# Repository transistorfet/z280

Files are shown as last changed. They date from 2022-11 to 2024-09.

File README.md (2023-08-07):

Z280 Computer
=============

###### *Started October 29, 2022*

A [series of] computers using the Z280, similar to the [Computie
project](https://jabberwocky.ca/projects/computie/).  The first board is a prototyping board with
the CPU's basic needs (clock/pullup resistors/etc), a 1MB Static RAM, a 1MB Flash chip, plus an
expansion bus that an Arduino can be connected to.  The bus pin assignments match Computie's
Supervisor shield, so the onboard flash chip can be programmed using the same harness as
[Computie](https://github.com/transistorfet/computie/raw/main/hardware/68k-Supervisor).

This repository uses git submodules, and can be cloned using:
```
git clone --recurse-submodules git@github.com:transistorfet/z280.git
```

Z280-SBC Revision 1
-------------------

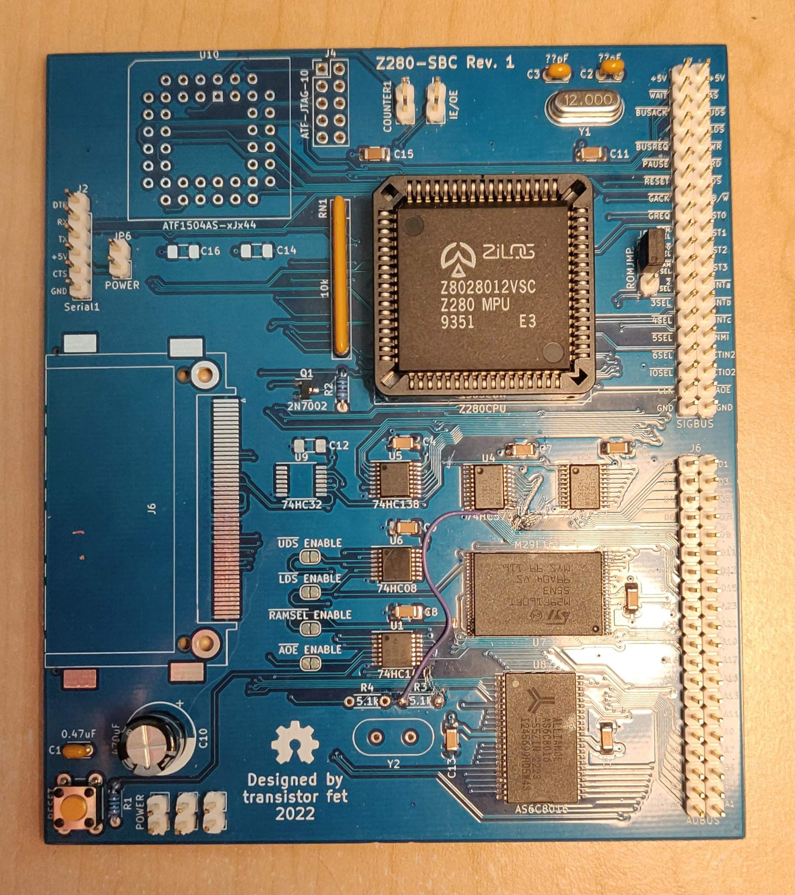
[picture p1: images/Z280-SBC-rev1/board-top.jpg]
Z280-SBC Rev. 1 Assembled Board Top


[Schematics](https://github.com/transistorfet/z280/raw/main/hardware/Z280-SBC/Z280-SBC.pdf)

I designed the first board quickly with the idea of it being rough.  Rather than prototype the CPU
using solderless breadboards, which are prone to electrical faults, I thought I'd design a minimal
board instead, with footprints for various additional components, like memory, a compact flash card
slot, and a CPLD.  I made the mistake of using vias that were 0.4 mm total diameter, which made the
boards more expensive at JLC.  If I redesign the board, I'll probably try to use 0.45 mm vias to
avoid that.

Building the board was pretty quick and easy.  I used the supervisor shield from Computie, along
with the Arduino program
[here](https://github.com/transistorfet/z280/raw/main/software/arduino/Z280Supervisor/) to try to
feed data to the CPU live, without the memory.  I couldn't find documentation on the frequency range
of the CPU, so I used a 12 MHz crystal, which clocks the CPU at 3 MHz.  That's still too fast
though for the Arduino to assert the WAIT signal without an external flip flop to latch it.

I added the memory to the board to see if I could get the CPU executing from there instead, but it
turns out the footprint for the flash chip is upside down, and I installed the chip right way up.  I
didn't notice at first, and while trying to read from the RAM I was getting duplicate numbers in the
test pattern because the A4 address line was being held always low by the flash chip.  The flash
chip was also getting extremely hot when programming the Arduino, but not when idle, oddly enough.
Eventually I clued into the fact that the chip needed to be rotated, and was able to do that using a
hot air rework station to remove the chip.  I reused the same chip, and it seems to work, but there
are other issues with the board, and I'm a bit suspicious of it still.

Using a [logic analyzer](https://www.sparkfun.com/products/18627), I captured some signals after a
reset (I held the reset button while starting a capture and released it during the capture to get
the initial startup).  The bus cycles didn't seem to make sense for the program it should have been
executing, so I programmed the halt instruction into each byte of the first 2K of the flash and ran
it to make sure it halted pretty much right away.  It accessed memory twice before halting instead
of just once, but that might be the instruction pre-fetch (not sure yet).

I was able to use the /DS line wired to the /WAIT line to pause the CPU on the first instruction,
and then inspect the address and data buses at that point, mid bus cycle.  The address bus had the
halt instruction (0x76) on the lower byte, as did the data bus.  The lower address and data buses
are multiplexed on this CPU, and the external latches are supposed to save the address portion when
/AS is low and output them on dedicated address lines wired to the separate address pins of the
memory chips.  Since this was just after a reset, it should have been accessing address 0x0000.  The
address demultiplexing latches should have taken care of this, but it was as if they were open all
the time.  Well, I got the logic backwards on the latch enable pin, so it was was latching when the
/AS line *wasn't* asserted (low).  I must have thought it was negative logic instead of positive
logic, because the /OE pin on the same chip to enable the output is negative logic.

I was able to use one of the inverter gates for the backup clock, which wasn't populated yet, to
invert the /AS line before going into the latch enable pin (positive-logic).  That fixed the
latching issue, and it seems to execute code now, but I can't get much visibility into it yet.

I looked at the ST0-ST3 signals in particular, which output a number corresponding to the
transaction type during each bus cycle.  It seems to be running as expected, accessing memory either
cacheable (0x8) or non-cacheable (0x9), and refreshing memory (0x1).  When the CPU halts, it issues
a halt bus cycle (0x3) and then only performs refresh cycles after that.

I tried adding an EPU instruction, which is a custom Z280 instruction for accessing a coprocessor.
It uses its own transaction type, 0xD for the first word, and 0xC for all subsequent words.  Writing
that instruction into the ROM produced those codes, so it's definitely executing code.  It seemed to
sometimes halt too early though, which turned out to be the attempt at configuring the MMU.  If
there's a problem with the page table that's loaded once the MMU is enabled, it will cause "the
fatal condition" to occur, which halts the CPU.  I had a number of mistakes in the code, and the Z80
assembler I was using was producing some incorrect code.  I switched to SDCC's assembler, which
produces correct code and correct byte orders, and the MMU can now be initialized without 

With that, I set about configuring the UART according to the [Z280 Technical
Manual](https://oldcomputers.dyndns.org/public/pub/rechner/zilog/z280/manual/index.html), which also
requires Timer1 to be configured.  It worked without much trouble, and I was able to print a message
to a serial terminal.

I will need to make a more capable monitor to write to flash so that I can load and jump to code in
RAM instead so I don't need to flash the arduino and then flash the onboard chip.  I can instead
load the data over the serial terminal into ram and run it, the way I can with Computie68k.

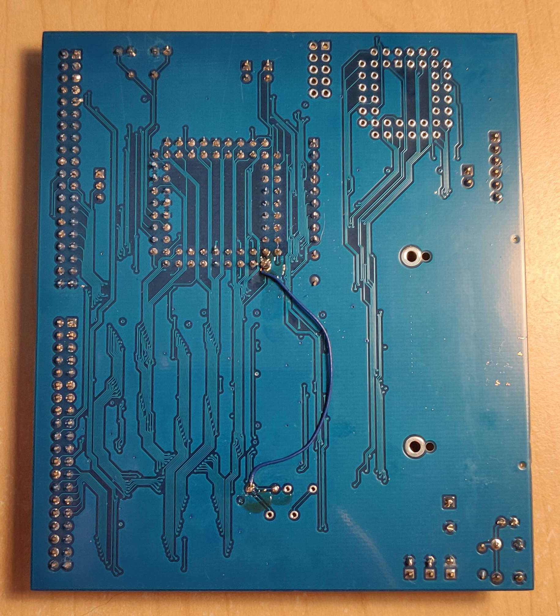
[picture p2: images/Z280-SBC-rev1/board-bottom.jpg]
Z280-SBC Rev. 1 Assembled Board Bottom


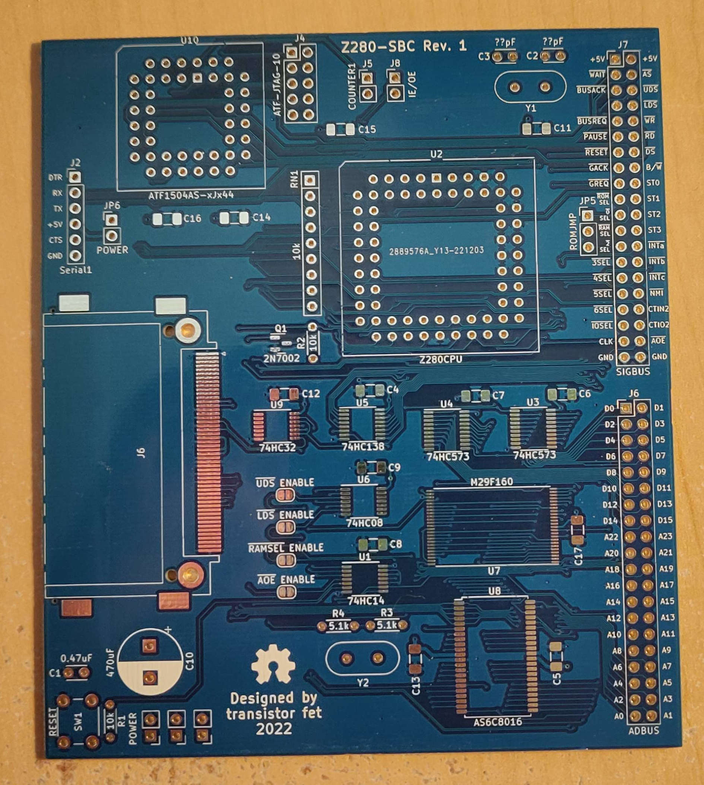
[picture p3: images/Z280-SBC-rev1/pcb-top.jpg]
Z280-SBC Rev. 1 PCB Top


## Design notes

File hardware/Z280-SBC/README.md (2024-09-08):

Z280-SBC
========

Status: DO NOT BUILD (see errata)

Latest: Rev.1

### About
A single board computer with a Z280 CPU, 1MB of static RAM, and 1MB of Flash.

This board has a number of issues described in the errata, which require reworking the board.  The
flash chip needs to be upside down, and the address selection latch's operation is backwards and
needs an extra inverter gate, it or won't run code.  Also, the serial port cannot function correctly
without an external clock circuit to directly supply the UART clock because driving it indirectly
with the Z280's timer causes frequent clock glitches resulting in invalid characters being
sent/received.

[Revision 1 Notes & Errata](revisions/Z280-SBC-rev1-errata.txt)

[Revision 1 Schematic](revisions/Z280-SBC-rev1.pdf)

[Revision 1 Gerbers](revisions/Z280-SBC-rev1.zip)

Z280-SBC board with a blue coloured solder mask and white pin headers, partially populated with the CPLD and CompactFlash slot left off
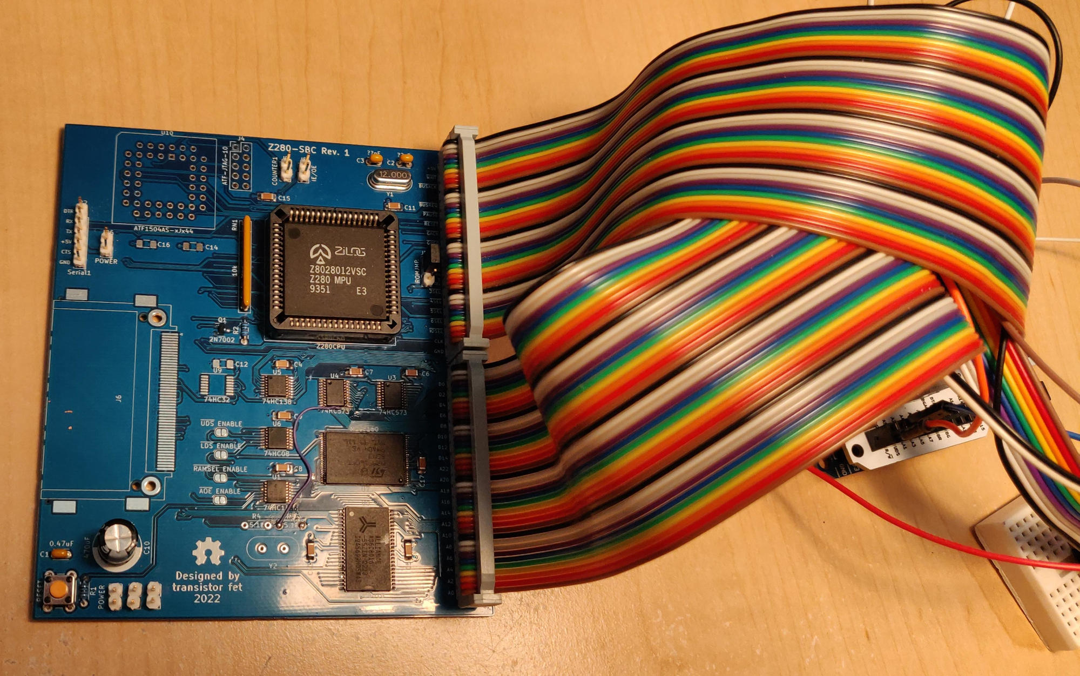
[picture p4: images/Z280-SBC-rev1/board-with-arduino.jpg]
Z280-SBC board with a blue coloured solder mask and white pin headers, and two rainbow/multi-coloured 40-pin ribbon cables connected to an ardunio with the Computie supervisor shield

Z280-SBC board unpopulated, showing the blue solder mask and white silk screen labels

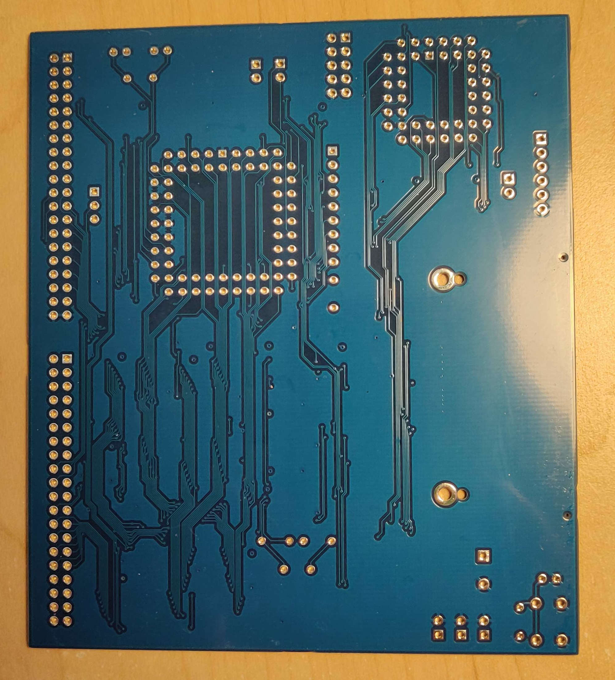
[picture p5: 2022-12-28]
images/Z280-SBC-rev1/pcb-bottom.jpg

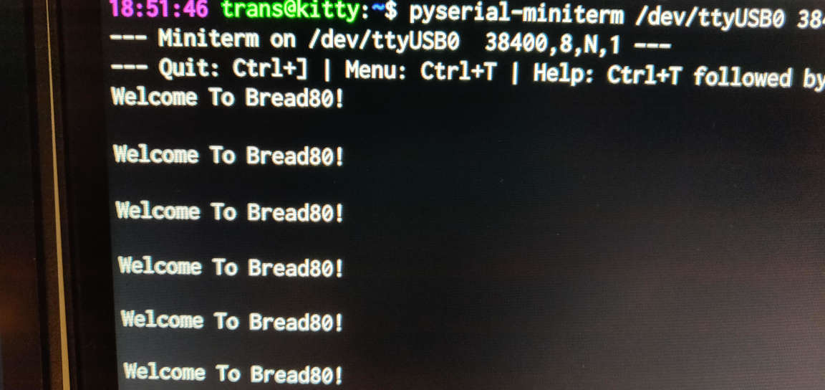
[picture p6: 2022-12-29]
images/Z280-SBC-rev1/z280-uart-message.jpg

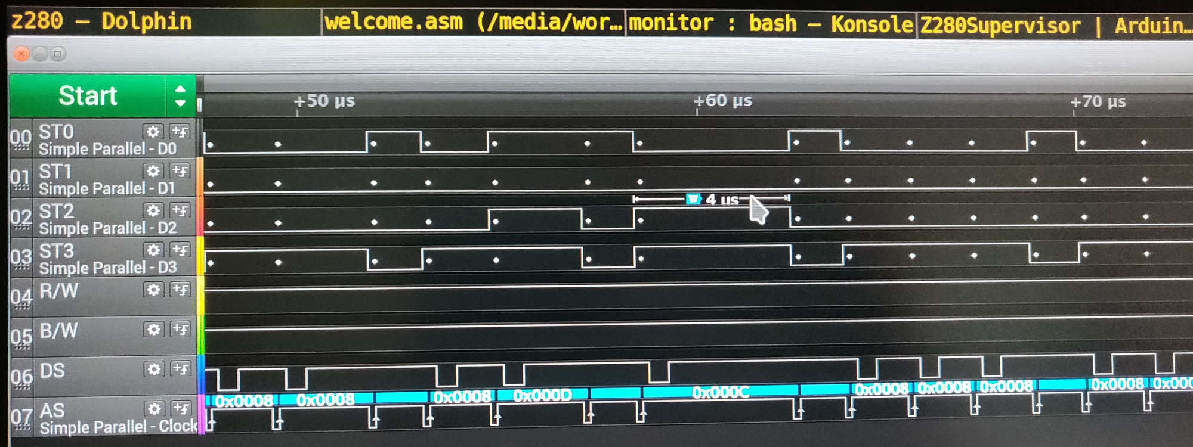
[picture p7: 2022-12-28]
images/Z280-SBC-rev1/z280-logic-analyzer.jpg

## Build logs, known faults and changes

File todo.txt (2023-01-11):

* should you use an MC68692 Serial Controller or something instead of the CPLD, or replace it with the 84 pin PLCC and hook up
  address and data pins (at least 8 data bits) to the I/O, so that you can emulate simple I/O
* CPLD could act as both an interrupt controller and bus coordinator (or rather, the local bus coordinator, where the global
  coordinator would be on the backplane).  This would be if you were trying the multiprocessor feature

* try using interrupts for serial to hopefully transfer data faster than otherwise

* the CPU reads the first 4 bytes of RAM as FFFF FFFF, which seems to still work because there are no other instructions, no int
  handlers that could get in the way, so it still executes code as expected
  Not sure if this is solved now? ^^
* boot in the monitor doesn't work, compiler error so it's commented out
* printf is sometimes glitchy

* to use the arduino, you'd really need to add a flip-flop for the wait state, which the arduino could manually activate via a pin
  on the control signals 40-pin connector to enable latching, but I'm mostly past the need for the arduino besides programming

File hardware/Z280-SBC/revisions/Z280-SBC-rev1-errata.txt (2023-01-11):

Revision 1 Errata and Notes
===========================

- Power connectors are upside-down (ground on top), and are unlabelled

- Somehow I managed to rotate the footprint for the flash chip.  Pin 1 is the bottom right corner instead of the top left.
  It should be possible to rotate the chip and get it working, but I've already mounted the chip the wrong way, and it's
  heated up quite a bit as a result.  Removing and rotating the chip fixed the issue.  It might not be as reliable as it
  should be, but the reversed chip does seem to be working most of the time

- I messed up the logic for latching the addresses with 74HC573s.  It's actually positive logic, so a high on the LE
  line of the will load the data bus into the address bus.  /AS is wired to it because we want it to latch only when /AS
  is low (address an AD bus is valid), which is backwards.  It needs to be inverted before going into LE. 

- the tty connector is rotated 180 degrees, such that the FTDI boards I have must go inward, towards the CPU instead of
  outward from the board.  It's probably because I copied the k30, and that one was already rotated 90 from the usual
  position, to come out of the top of the board

- there seems to be a problem with Timer1 running off the CPU clock when used as the UART clock.  It seems to glitch no
  matter what, when receiving data, regardless of the configuration of Timer1 or the UART .  An external clock wired to
  Timer1 input fixes the issue, but I've repurposed the alternate clock's inverters to fix the latches, so the clock is on
  an external breadboad.

- I put CTIN1 and CTIN2 onto input-only pins of the CPLD, when they should be output pins (input to the CPU, output from
  the CPLD).  I need to use CTIN1 as the alternate clock input

- the CPLD is kind of useless because it doesn't have any extra I/O pins that could be hooked up to other devices, such
  as an I2C connection to other devices, or chip select lines to index devices based on the address lines.  I probably
  should have put the bigger PLCC84 chip on and wired the extra I/O to generic header pins.  Maybe included the data bus
  so that simple I/O devices could be emulated, but that might require too many macrocells and would be better for an FPGA

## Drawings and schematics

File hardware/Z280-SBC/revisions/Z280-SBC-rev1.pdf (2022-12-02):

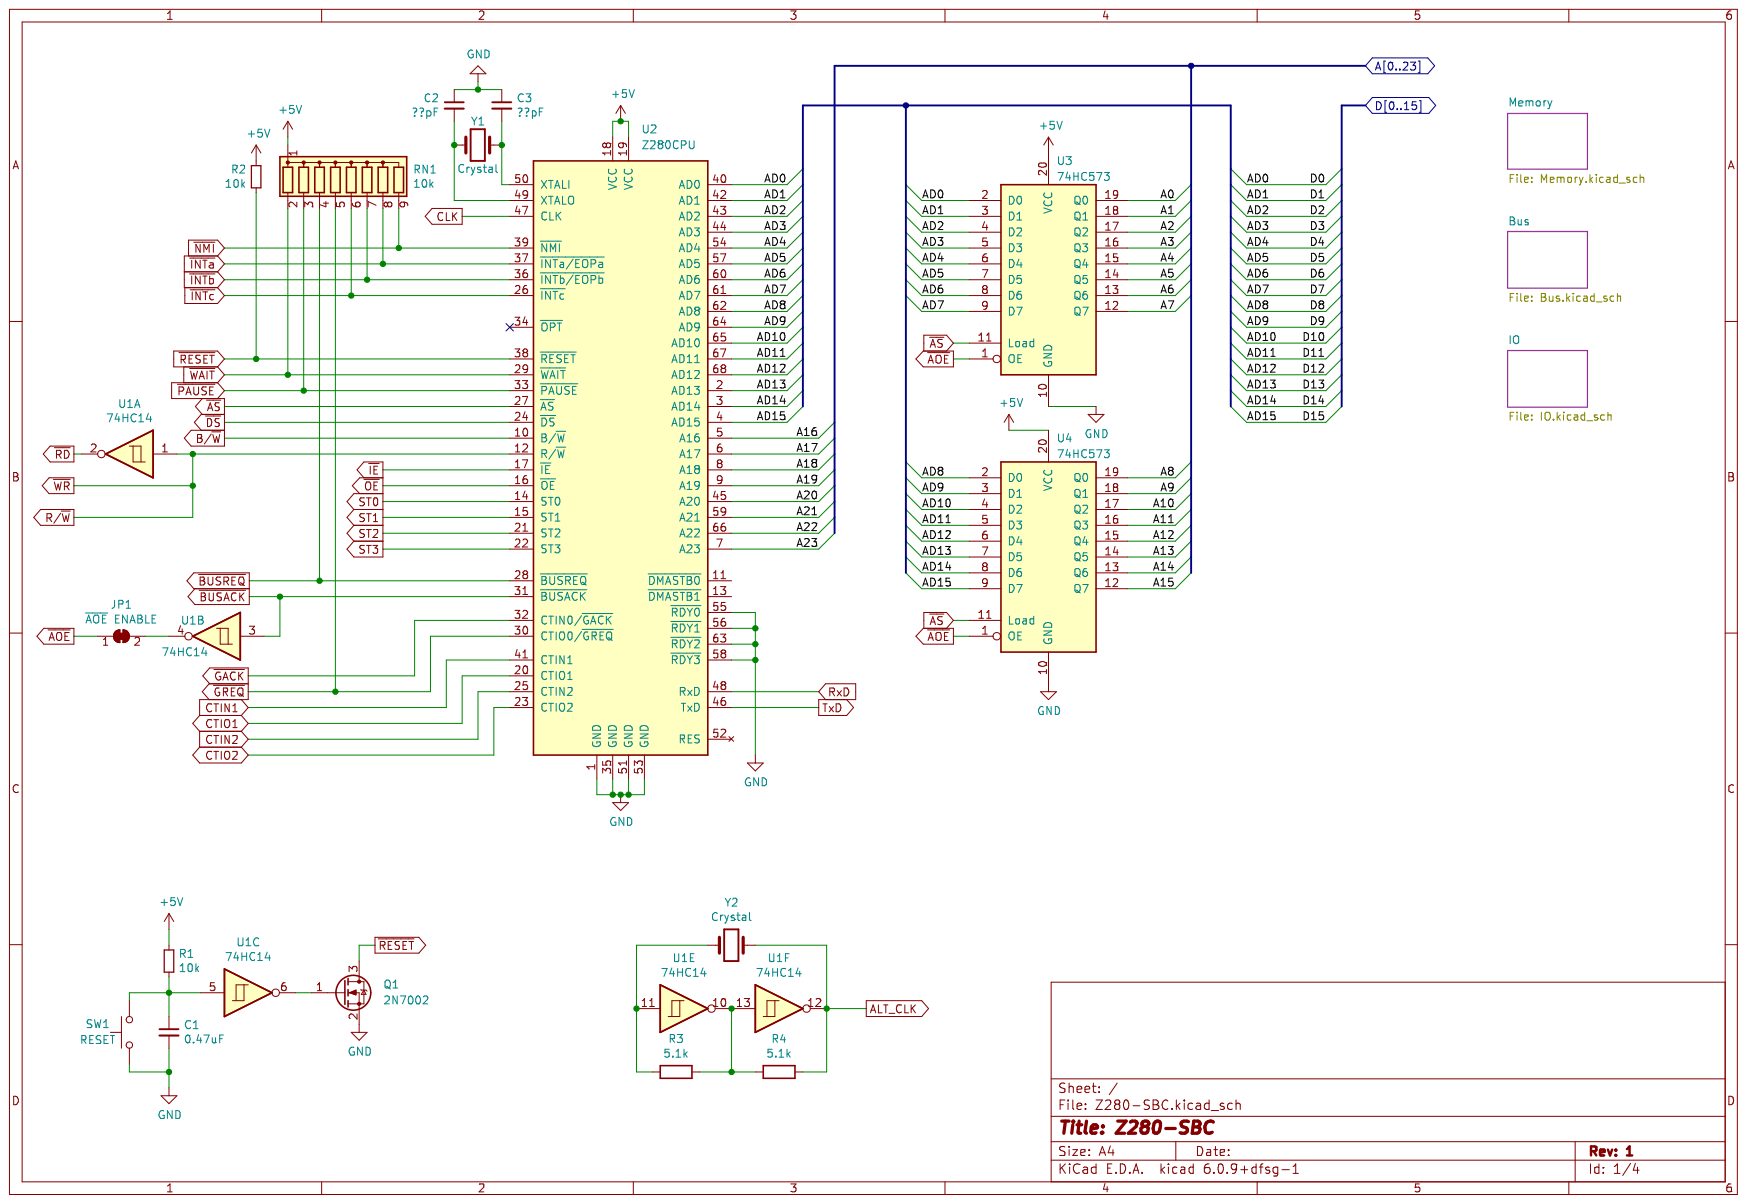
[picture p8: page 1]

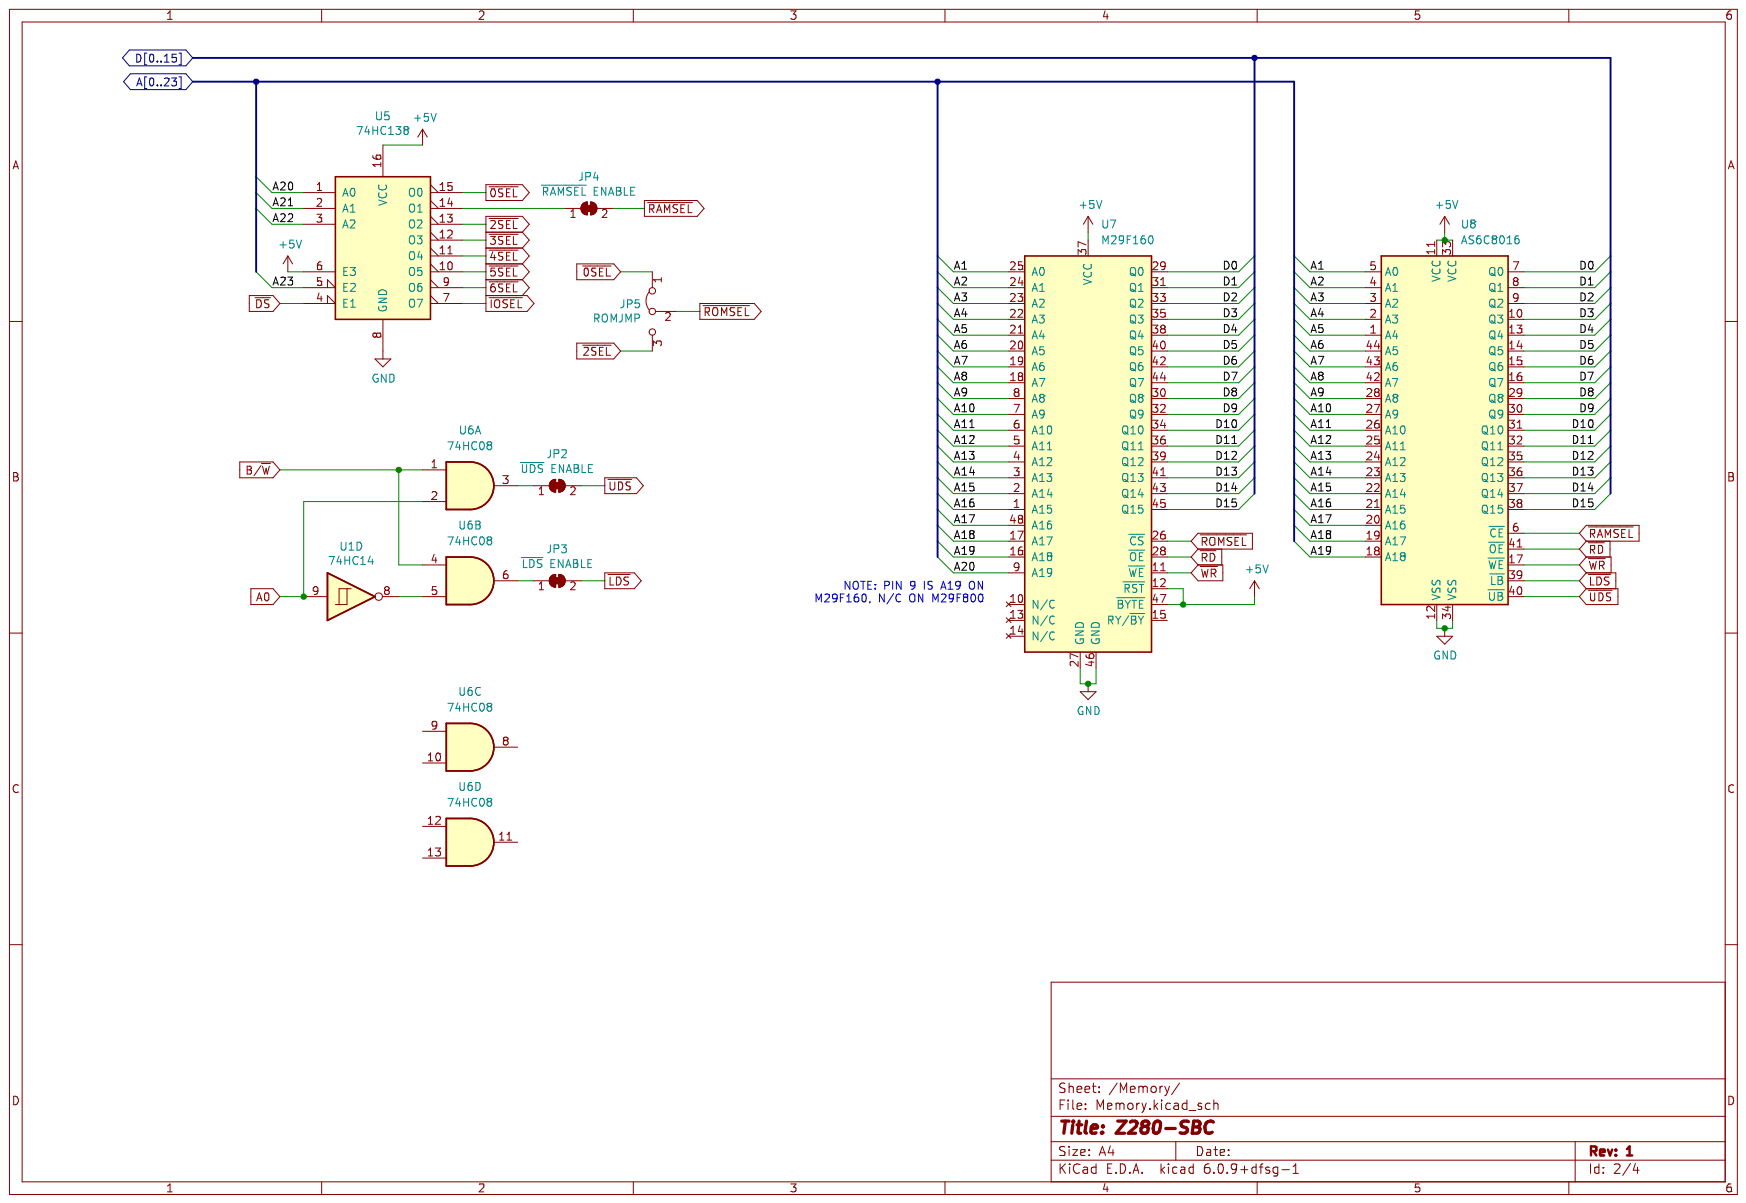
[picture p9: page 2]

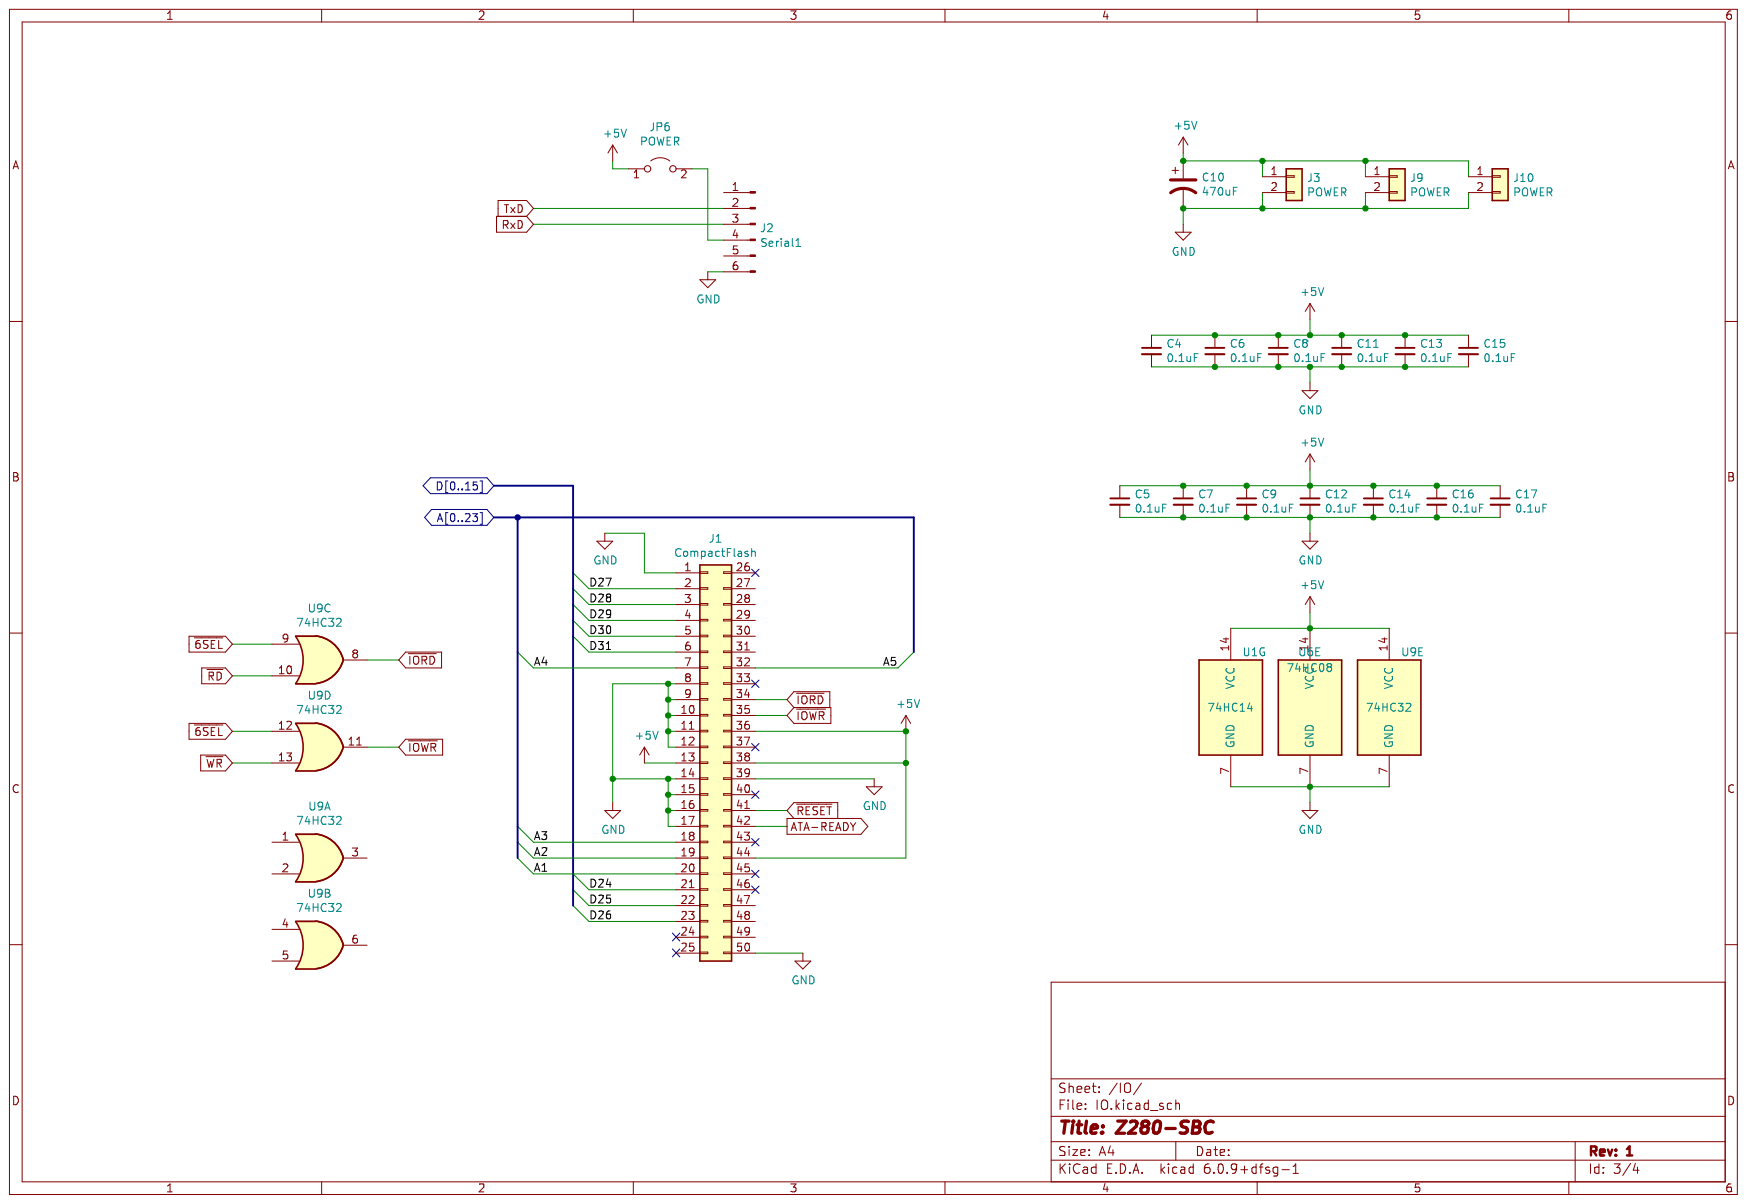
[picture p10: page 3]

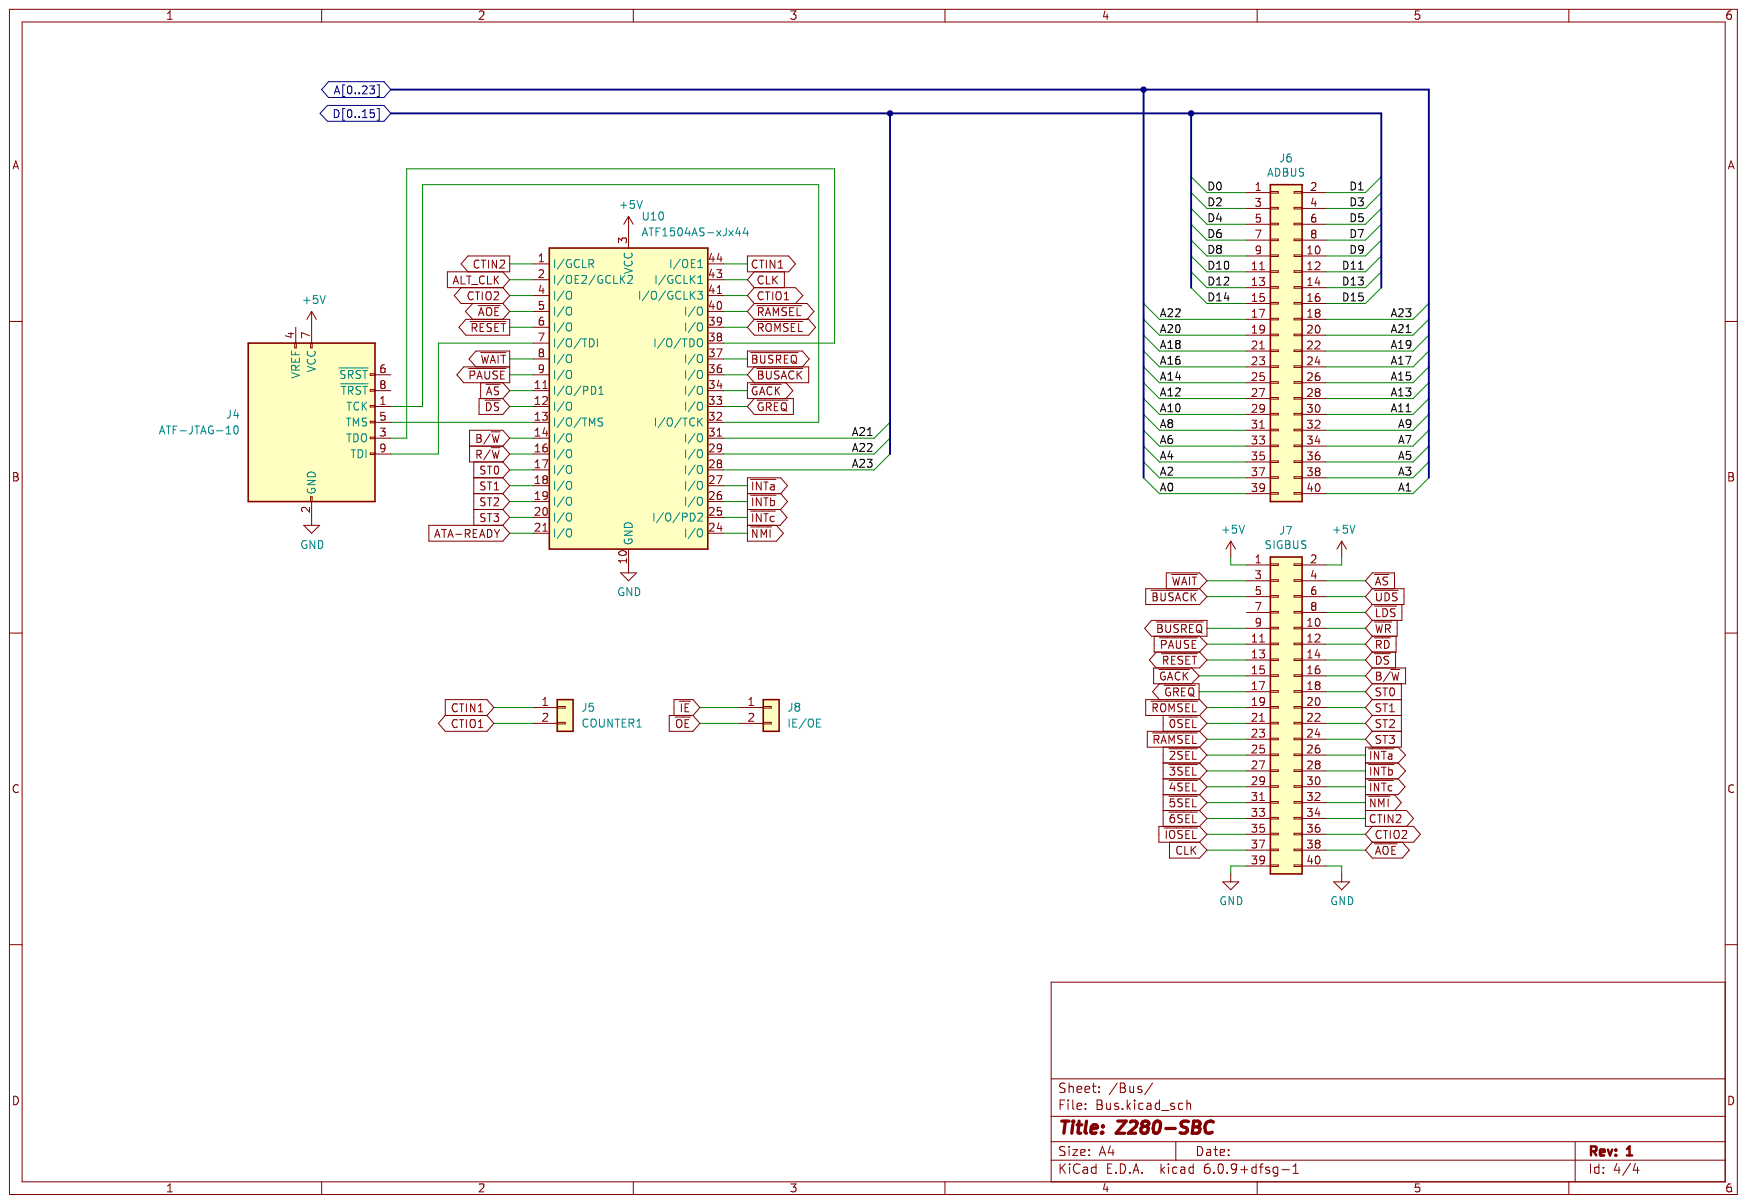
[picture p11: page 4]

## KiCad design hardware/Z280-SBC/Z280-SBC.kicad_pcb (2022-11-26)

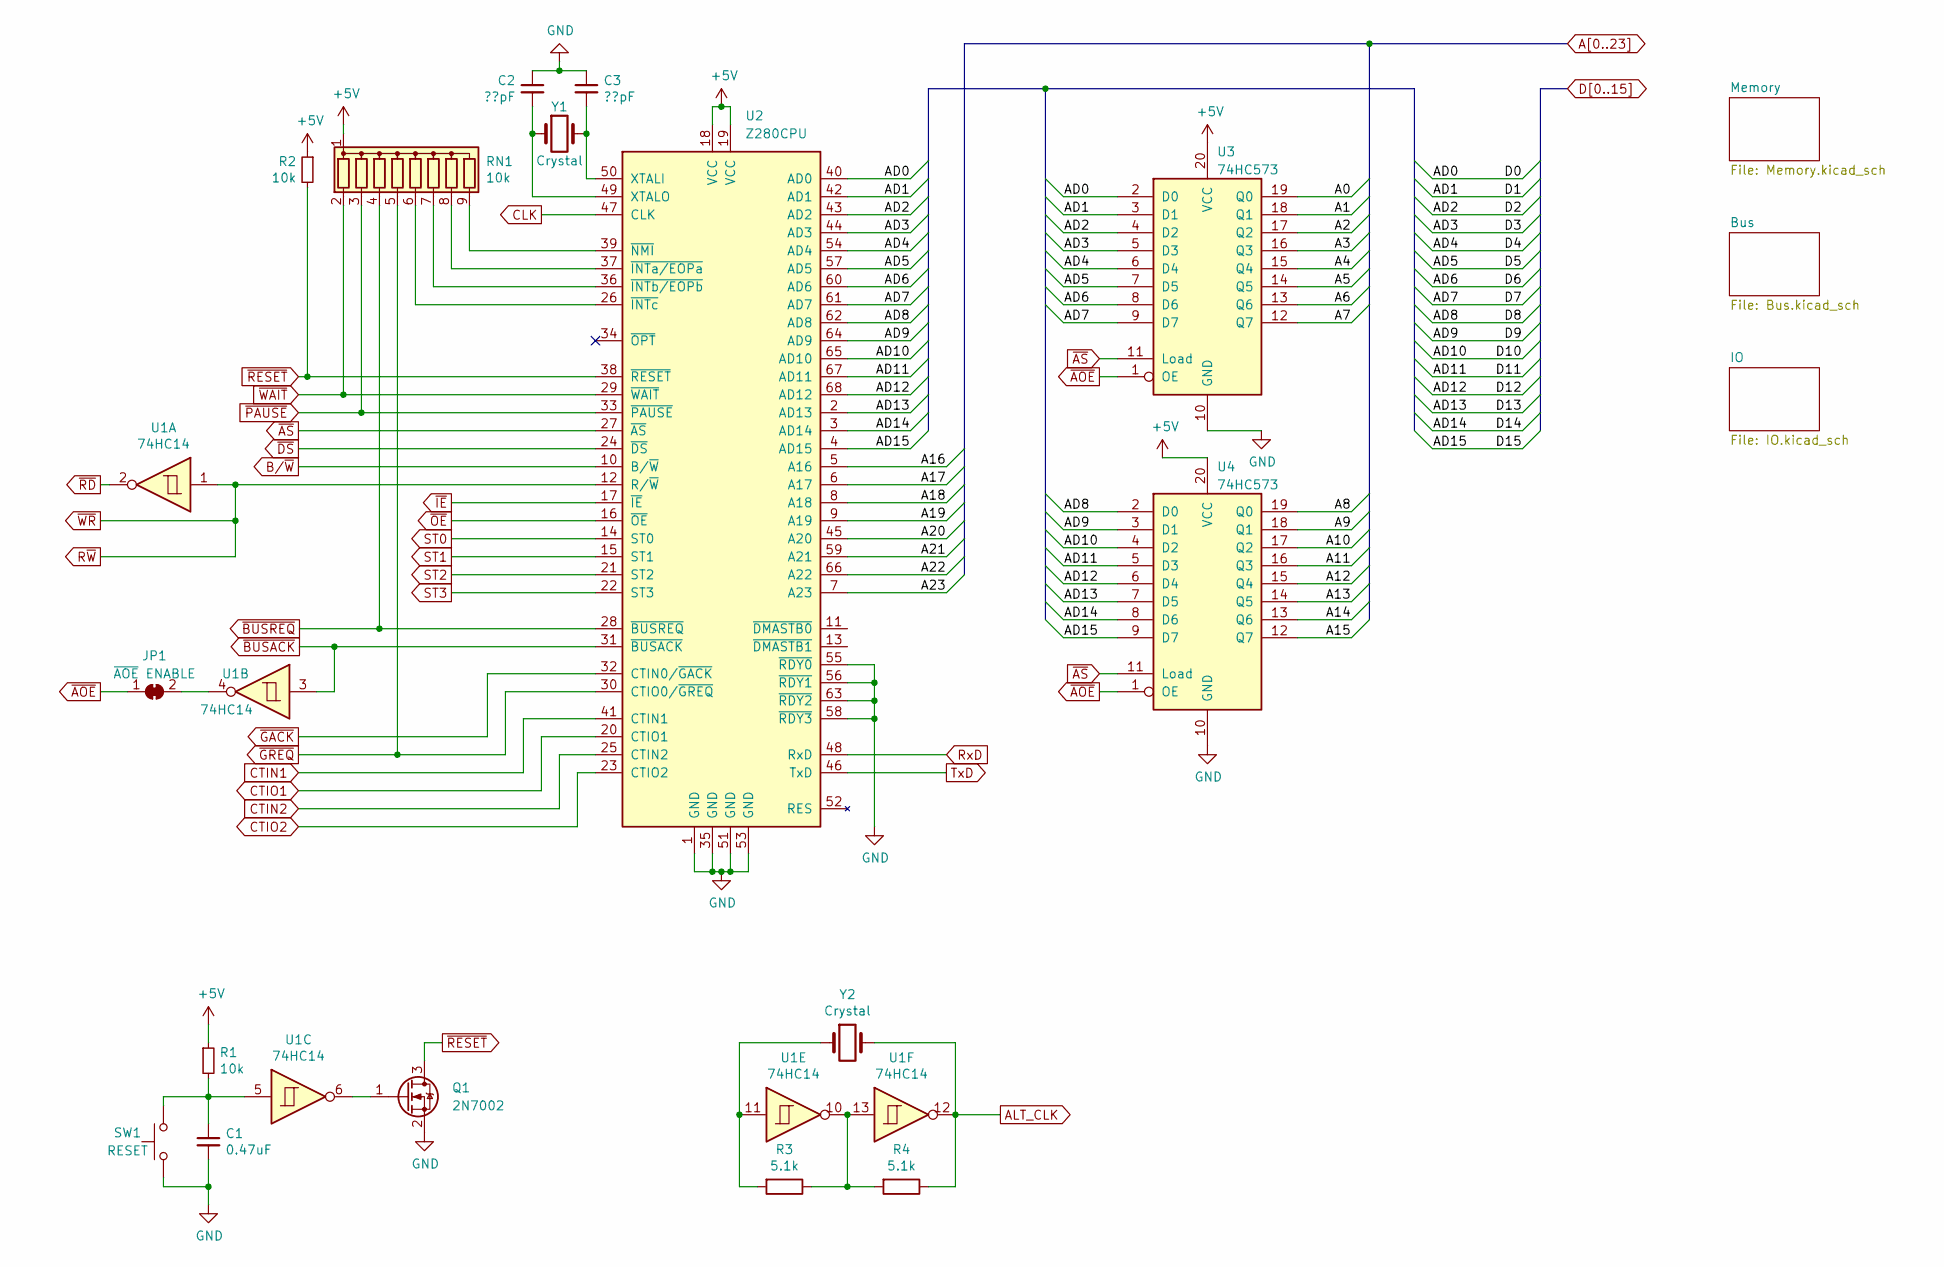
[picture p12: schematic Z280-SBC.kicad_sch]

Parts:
C1: 0.47uF; C_Disc_D3.0mm_W2.0mm_P2.50mm
C2, C3: ??pF; C_Disc_D3.0mm_W2.0mm_P2.50mm
JP1: ~{AOE} ENABLE; SolderJumper-2_P1.3mm_Bridged_RoundedPad1.0x1.5mm
Q1: 2N7002; SOT-23
R1, R2: 10k; R_Axial_DIN0204_L3.6mm_D1.6mm_P5.08mm_Horizontal
R3, R4: 5.1k; R_Axial_DIN0204_L3.6mm_D1.6mm_P5.08mm_Horizontal
RN1: 10k; R_Array_SIP9
SW1: RESET; SW_PUSH_6mm
U1: 74HC14; TSSOP-14_4.4x5mm_P0.65mm
U2: Z280CPU; PLCC-68_THT-Socket
U3, U4: 74HC573; TSSOP-20_4.4x6.5mm_P0.65mm
Y1, Y2: Crystal; Crystal_HC49-4H_Vertical

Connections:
+5V: R1.1, R2.1, RN1.1 (common), U2.18 (VCC), U2.19 (VCC), U3.20 (VCC), U4.20 (VCC); also elsewhere on the board
A0: U3.19 (Q0); also elsewhere on the board
A1: U3.18 (Q1); also elsewhere on the board
A2: U3.17 (Q2); also elsewhere on the board
A3: U3.16 (Q3); also elsewhere on the board
A4: U3.15 (Q4); also elsewhere on the board
A5: U3.14 (Q5); also elsewhere on the board
A6: U3.13 (Q6); also elsewhere on the board
A7: U3.12 (Q7); also elsewhere on the board
A8: U4.19 (Q0); also elsewhere on the board
A9: U4.18 (Q1); also elsewhere on the board
A10: U4.17 (Q2); also elsewhere on the board
A11: U4.16 (Q3); also elsewhere on the board
A12: U4.15 (Q4); also elsewhere on the board
A13: U4.14 (Q5); also elsewhere on the board
A14: U4.13 (Q6); also elsewhere on the board
A15: U4.12 (Q7); also elsewhere on the board
A16: U2.5 (A16); also elsewhere on the board
A17: U2.6 (A17); also elsewhere on the board
A18: U2.8 (A18); also elsewhere on the board
A19: U2.9 (A19); also elsewhere on the board
A20: U2.45 (A20); also elsewhere on the board
A21: U2.59 (A21); also elsewhere on the board
A22: U2.66 (A22); also elsewhere on the board
A23: U2.7 (A23); also elsewhere on the board
ALT_CLK: R4.1, U1.12, Y2.2; also elsewhere on the board
B/~W: U2.10 (B/~W); also elsewhere on the board
CLK: U2.47 (CLK); also elsewhere on the board
CTIN1: U2.41 (CTIN1); also elsewhere on the board
CTIN2: U2.25 (CTIN2); also elsewhere on the board
CTIO1: U2.20 (CTIO1); also elsewhere on the board
CTIO2: U2.23 (CTIO2); also elsewhere on the board
D0: U2.40 (AD0), U3.2 (D0); also elsewhere on the board
D1: U2.42 (AD1), U3.3 (D1); also elsewhere on the board
D2: U2.43 (AD2), U3.4 (D2); also elsewhere on the board
D3: U2.44 (AD3), U3.5 (D3); also elsewhere on the board
D4: U2.54 (AD4), U3.6 (D4); also elsewhere on the board
D5: U2.57 (AD5), U3.7 (D5); also elsewhere on the board
D6: U2.60 (AD6), U3.8 (D6); also elsewhere on the board
D7: U2.61 (AD7), U3.9 (D7); also elsewhere on the board
D8: U2.62 (AD8), U4.2 (D0); also elsewhere on the board
D9: U2.64 (AD9), U4.3 (D1); also elsewhere on the board
D10: U2.65 (AD10), U4.4 (D2); also elsewhere on the board
D11: U2.67 (AD11), U4.5 (D3); also elsewhere on the board
D12: U2.68 (AD12), U4.6 (D4); also elsewhere on the board
D13: U2.2 (AD13), U4.7 (D5); also elsewhere on the board
D14: U2.3 (AD14), U4.8 (D6); also elsewhere on the board
D15: U2.4 (AD15), U4.9 (D7); also elsewhere on the board
GND: C1.2, C2.1, C3.1, Q1.2 (S), SW1.1, U2.1 (GND), U2.35 (GND), U2.51 (GND), U2.53 (GND), U2.55 (~RDY0), U2.56 (~RDY1), U2.58 (~RDY3), U2.63 (~RDY2), U3.10 (GND), U4.10 (GND); also elsewhere on the board
unnamed: C1.1, R1.2, SW1.2, U1.5
unnamed: C2.2, U2.49 (XTALO), Y1.1
unnamed: C3.2, U2.50 (XTALI), Y1.2
unnamed: JP1.2 (B), U1.4
unnamed: Q1.1 (G), U1.6
unnamed: R3.1, R4.2, U1.10, U1.13
unnamed: R3.2, U1.11, Y2.1
unnamed: RN1.6 (R5), U2.26 (~INTc)
unnamed: RN1.7 (R6), U2.36 (~INTb/EOPb)
unnamed: RN1.8 (R7), U2.37 (~INTa/EOPa)
unnamed: RN1.9 (R8), U2.39 (~NMI)
RxD: U2.48 (RxD); also elsewhere on the board
R~W: U1.1, U2.12 (R/~W); also elsewhere on the board
ST0: U2.14 (ST0); also elsewhere on the board
ST1: U2.15 (ST1); also elsewhere on the board
ST2: U2.21 (ST2); also elsewhere on the board
ST3: U2.22 (ST3); also elsewhere on the board
TxD: U2.46 (TxD); also elsewhere on the board
~AOE: JP1.1 (A), U3.1 (OE), U4.1 (OE); also elsewhere on the board
~AS: U2.27 (~AS), U3.11 (Load), U4.11 (Load); also elsewhere on the board
~BUSACK: U1.3, U2.31 (~BUSACK); also elsewhere on the board
~BUSREQ: RN1.4 (R3), U2.28 (~BUSREQ); also elsewhere on the board
~DS: U2.24 (~DS); also elsewhere on the board
~GACK: U2.32 (CTIN0/~GACK); also elsewhere on the board
~GREQ: RN1.5 (R4), U2.30 (CTIO0/~GREQ); also elsewhere on the board
~IE: U2.17 (~IE); also elsewhere on the board
~OE: U2.16 (~OE); also elsewhere on the board
~PAUSE: RN1.3 (R2), U2.33 (~PAUSE); also elsewhere on the board
~RD: U1.2; also elsewhere on the board
~RESET: Q1.3 (D), R2.2, U2.38 (~RESET); also elsewhere on the board
~WAIT: RN1.2 (R1), U2.29 (~WAIT); also elsewhere on the board

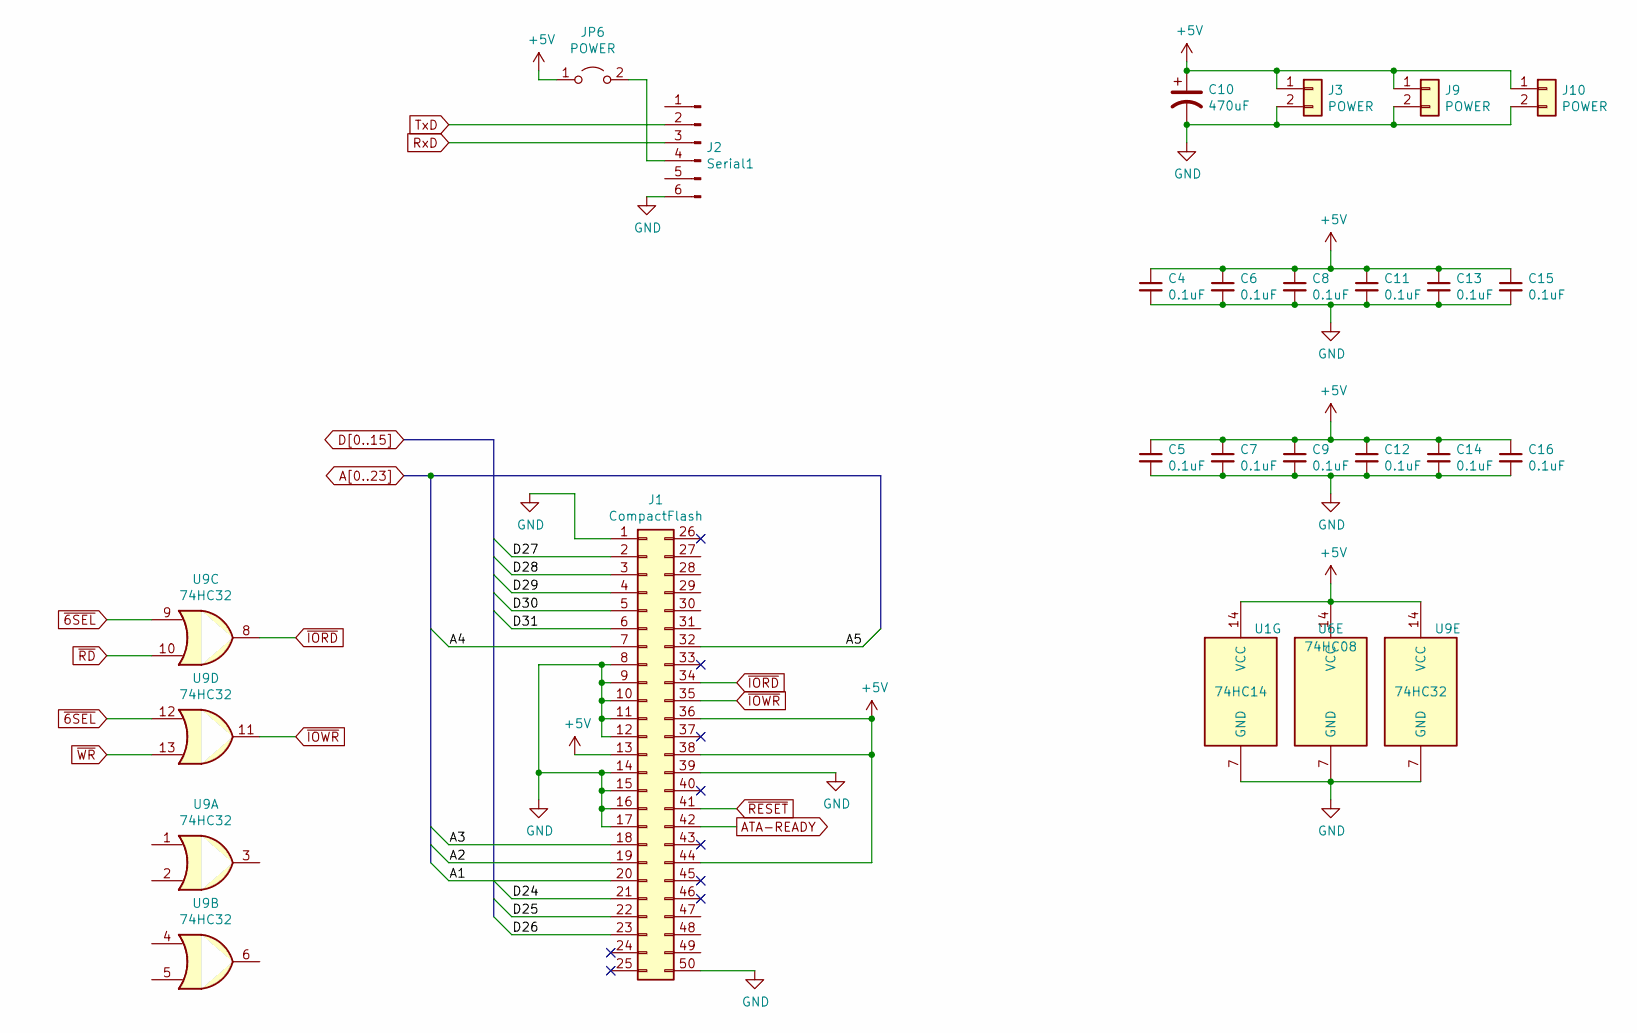
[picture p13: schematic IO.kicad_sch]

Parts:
C4, C5, C6, C7, C8, C9, C11, C12, C13, C14, C15, C16: 0.1uF; C_1206_3216Metric_Pad1.33x1.80mm_HandSolder
C10: 470uF; CP_Radial_D10.0mm_P5.00mm
J1: CompactFlash; CF-Card_3M_N7E50-Q516RB-40
J2: Serial1; PinHeader_1x06_P2.54mm_Vertical
J3, J9, J10: POWER; PinHeader_1x02_P2.54mm_Vertical
JP6: POWER; PinHeader_1x02_P2.54mm_Vertical
U1: 74HC14; TSSOP-14_4.4x5mm_P0.65mm
U6: 74HC08; TSSOP-14_4.4x5mm_P0.65mm
U9: 74HC32; TSSOP-14_4.4x5mm_P0.65mm

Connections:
+5V: C4.1, C5.1, C6.1, C7.1, C8.1, C9.1, C10.1, C11.1, C12.1, C13.1, C14.1, C15.1, C16.1, J1.13, J1.36, J1.38, J1.44, J3.1, J9.1, J10.1, JP6.1 (A), U1.14 (VCC), U6.14 (VCC), U9.14 (VCC); also elsewhere on the board
/IO/D24: J1.21
/IO/D25: J1.22
/IO/D26: J1.23
/IO/D27: J1.2
/IO/D28: J1.3
/IO/D29: J1.4
/IO/D30: J1.5
/IO/D31: J1.6
A1: J1.20; also elsewhere on the board
A2: J1.19; also elsewhere on the board
A3: J1.18; also elsewhere on the board
A4: J1.7; also elsewhere on the board
A5: J1.32; also elsewhere on the board
ATA-READY: J1.42; also elsewhere on the board
GND: C4.2, C5.2, C6.2, C7.2, C8.2, C9.2, C10.2, C11.2, C12.2, C13.2, C14.2, C15.2, C16.2, J1.1, J1.8, J1.9, J1.10, J1.11, J1.12, J1.14, J1.15, J1.16, J1.17, J1.39, J1.50, J2.6, J3.2, J9.2, J10.2, U1.7 (GND), U6.7 (GND), U9.7 (GND); also elsewhere on the board
unnamed: J2.4, JP6.2 (B)
RxD: J2.3; also elsewhere on the board
R~W: U9.13; also elsewhere on the board
TxD: J2.2; also elsewhere on the board
~6SEL: U9.9, U9.12; also elsewhere on the board
~IORD: J1.34, U9.8
~IOWR: J1.35, U9.11
~RD: U9.10; also elsewhere on the board
~RESET: J1.41; also elsewhere on the board

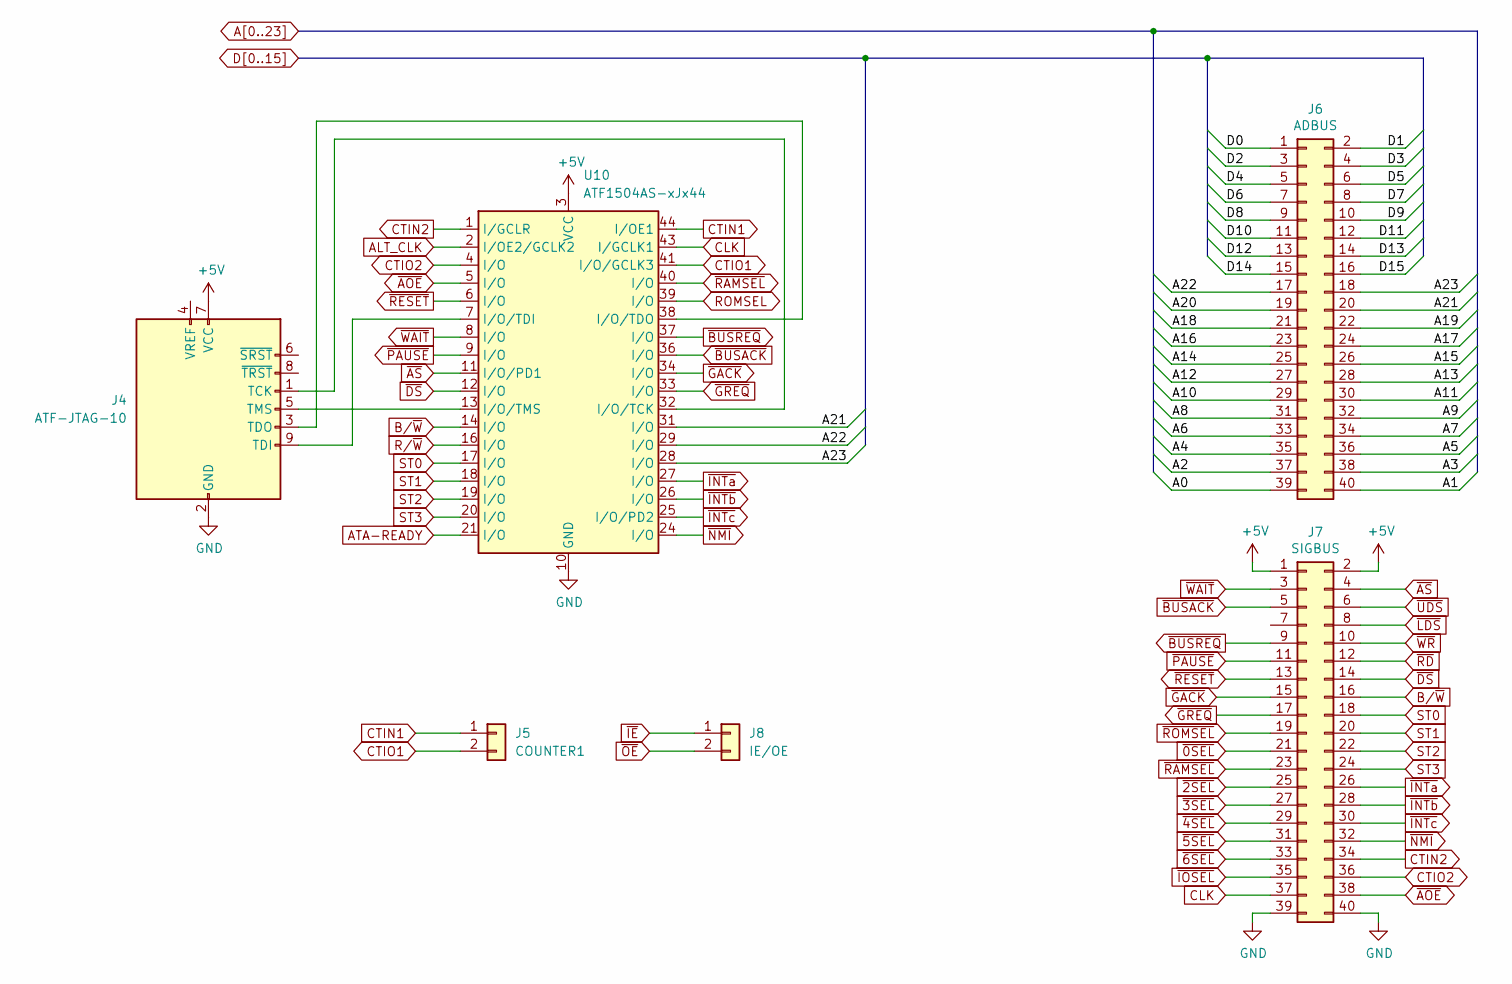
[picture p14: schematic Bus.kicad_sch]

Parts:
J4: ATF-JTAG-10; PinHeader_2x05_P2.54mm_Vertical
J5: COUNTER1; PinHeader_1x02_P2.54mm_Vertical
J6: ADBUS; PinHeader_2x20_P2.54mm_Vertical
J7: SIGBUS; PinHeader_2x20_P2.54mm_Vertical
J8: IE/OE; PinHeader_1x02_P2.54mm_Vertical
U10: ATF1504AS-xJx44; PLCC-44_THT-Socket

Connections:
+5V: J4.7 (VCC), J7.1, J7.2, U10.3 (VCC), U10.15 (VCC), U10.23 (VCC), U10.35 (VCC); also elsewhere on the board
A0: J6.39; also elsewhere on the board
A1: J6.40; also elsewhere on the board
A2: J6.37; also elsewhere on the board
A3: J6.38; also elsewhere on the board
A4: J6.35; also elsewhere on the board
A5: J6.36; also elsewhere on the board
A6: J6.33; also elsewhere on the board
A7: J6.34; also elsewhere on the board
A8: J6.31; also elsewhere on the board
A9: J6.32; also elsewhere on the board
A10: J6.29; also elsewhere on the board
A11: J6.30; also elsewhere on the board
A12: J6.27; also elsewhere on the board
A13: J6.28; also elsewhere on the board
A14: J6.25; also elsewhere on the board
A15: J6.26; also elsewhere on the board
A16: J6.23; also elsewhere on the board
A17: J6.24; also elsewhere on the board
A18: J6.21; also elsewhere on the board
A19: J6.22; also elsewhere on the board
A20: J6.19; also elsewhere on the board
A21: J6.20, U10.31 (I/O); also elsewhere on the board
A22: J6.17, U10.29 (I/O); also elsewhere on the board
A23: J6.18, U10.28 (I/O); also elsewhere on the board
ALT_CLK: U10.2 (I/OE2/GCLK2); also elsewhere on the board
ATA-READY: U10.21 (I/O); also elsewhere on the board
B/~W: J7.16, U10.14 (I/O); also elsewhere on the board
CLK: J7.37, U10.43 (I/GCLK1); also elsewhere on the board
CTIN1: J5.1, U10.44 (I/OE1); also elsewhere on the board
CTIN2: J7.34, U10.1 (I/GCLR); also elsewhere on the board
CTIO1: J5.2, U10.41 (I/O/GCLK3); also elsewhere on the board
CTIO2: J7.36, U10.4 (I/O); also elsewhere on the board
D0: J6.1; also elsewhere on the board
D1: J6.2; also elsewhere on the board
D2: J6.3; also elsewhere on the board
D3: J6.4; also elsewhere on the board
D4: J6.5; also elsewhere on the board
D5: J6.6; also elsewhere on the board
D6: J6.7; also elsewhere on the board
D7: J6.8; also elsewhere on the board
D8: J6.9; also elsewhere on the board
D9: J6.10; also elsewhere on the board
D10: J6.11; also elsewhere on the board
D11: J6.12; also elsewhere on the board
D12: J6.13; also elsewhere on the board
D13: J6.14; also elsewhere on the board
D14: J6.15; also elsewhere on the board
D15: J6.16; also elsewhere on the board
GND: J4.2 (GND), J4.10 (GND), J7.39, J7.40, U10.10 (GND), U10.22 (GND), U10.30 (GND), U10.42 (GND); also elsewhere on the board
unnamed: J4.1 (TCK), U10.32 (I/O/TCK)
unnamed: J4.3 (TDO), U10.38 (I/O/TDO)
unnamed: J4.5 (TMS), U10.13 (I/O/TMS)
unnamed: J4.9 (TDI), U10.7 (I/O/TDI)
ROMSEL: U10.39 (I/O)
R/~W: U10.16 (I/O)
R~W: J7.10; also elsewhere on the board
ST0: J7.18, U10.17 (I/O); also elsewhere on the board
ST1: J7.20, U10.18 (I/O); also elsewhere on the board
ST2: J7.22, U10.19 (I/O); also elsewhere on the board
ST3: J7.24, U10.20 (I/O); also elsewhere on the board
~0SEL: J7.21; also elsewhere on the board
~2SEL: J7.25; also elsewhere on the board
~3SEL: J7.27; also elsewhere on the board
~4SEL: J7.29; also elsewhere on the board
~5SEL: J7.31; also elsewhere on the board
~6SEL: J7.33; also elsewhere on the board
~AOE: J7.38, U10.5 (I/O); also elsewhere on the board
~AS: J7.4, U10.11 (I/O/PD1); also elsewhere on the board
~BUSACK: J7.5, U10.36 (I/O); also elsewhere on the board
~BUSREQ: J7.9, U10.37 (I/O); also elsewhere on the board
~DS: J7.14, U10.12 (I/O); also elsewhere on the board
~GACK: J7.15, U10.34 (I/O); also elsewhere on the board
~GREQ: J7.17, U10.33 (I/O); also elsewhere on the board
~IE: J8.1; also elsewhere on the board
~INTa: J7.26, U10.27 (I/O)
~INTb: J7.28, U10.26 (I/O)
~INTc: J7.30, U10.25 (I/O/PD2)
~IOSEL: J7.35; also elsewhere on the board
~LDS: J7.8; also elsewhere on the board
~NMI: J7.32, U10.24 (I/O)
~OE: J8.2; also elsewhere on the board
~PAUSE: J7.11, U10.9 (I/O); also elsewhere on the board
~RAMSEL: J7.23, U10.40 (I/O); also elsewhere on the board
~RD: J7.12; also elsewhere on the board
~RESET: J7.13, U10.6 (I/O); also elsewhere on the board
~ROMSEL: J7.19; also elsewhere on the board
~UDS: J7.6; also elsewhere on the board
~WAIT: J7.3, U10.8 (I/O); also elsewhere on the board

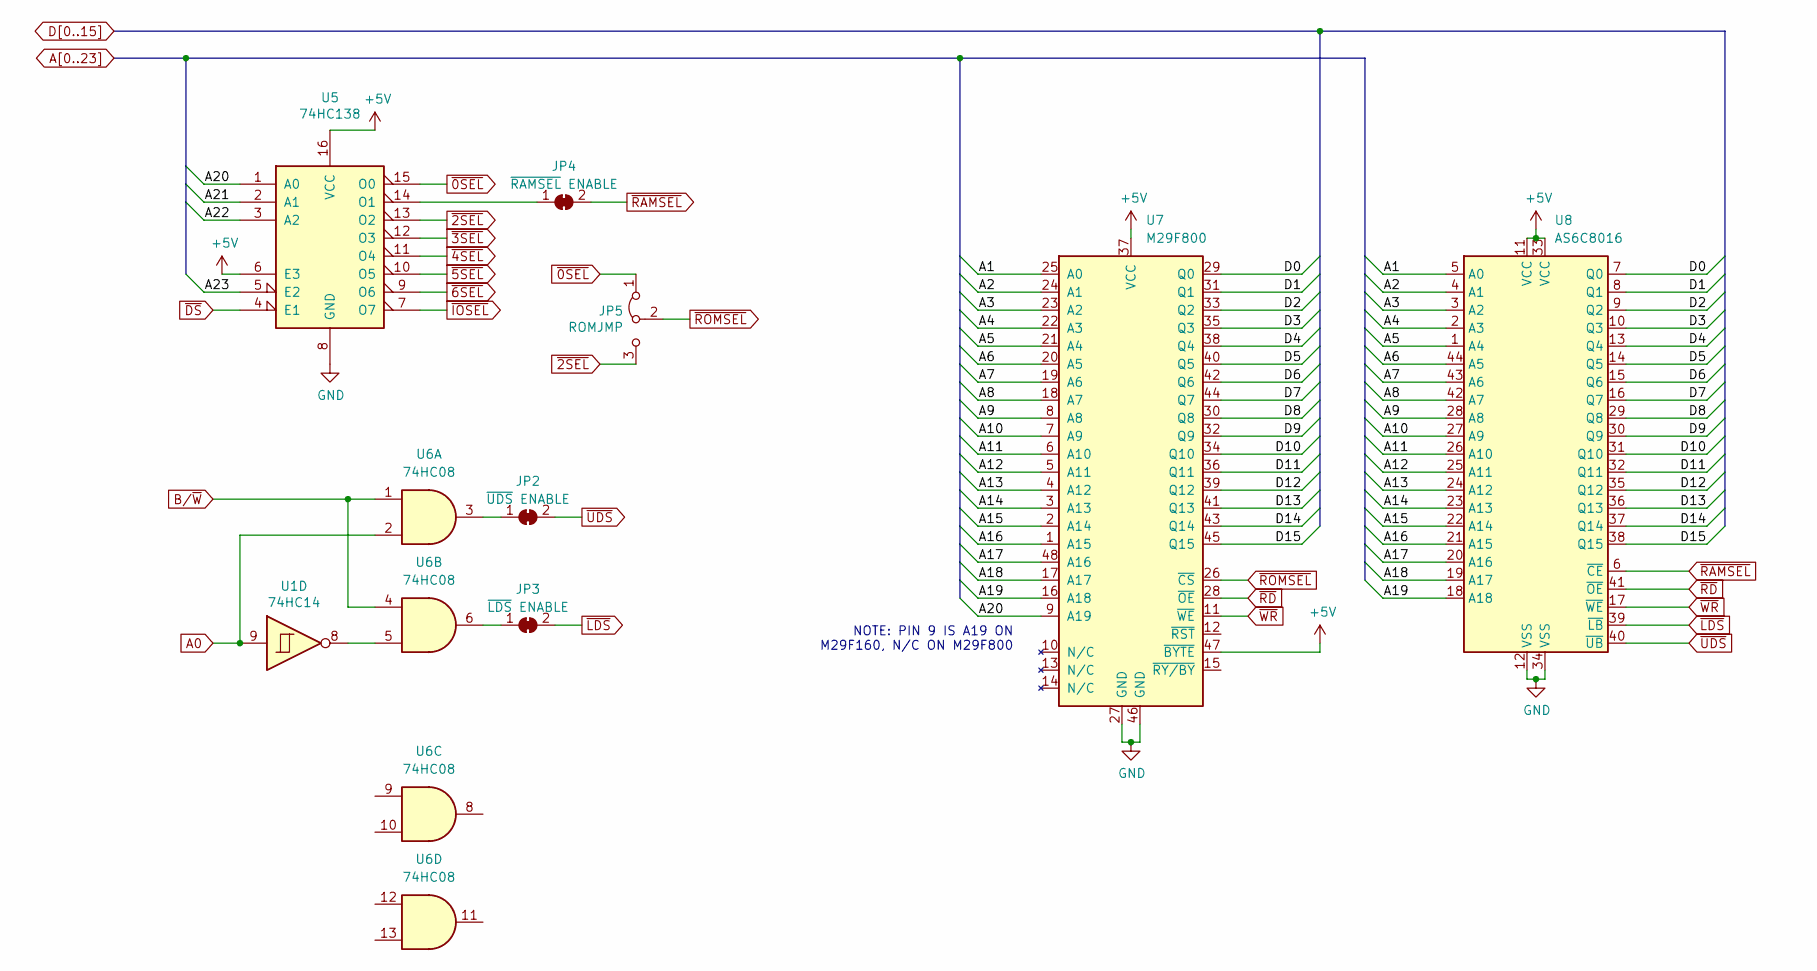
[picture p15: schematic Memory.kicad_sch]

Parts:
JP2: ~{UDS} ENABLE; SolderJumper-2_P1.3mm_Bridged_RoundedPad1.0x1.5mm
JP3: ~{LDS} ENABLE; SolderJumper-2_P1.3mm_Bridged_RoundedPad1.0x1.5mm
JP4: ~{RAMSEL} ENABLE; SolderJumper-2_P1.3mm_Bridged_RoundedPad1.0x1.5mm
JP5: ROMJMP; PinHeader_1x03_P2.54mm_Vertical
U1: 74HC14; TSSOP-14_4.4x5mm_P0.65mm
U5: 74HC138; TSSOP-16_4.4x5mm_P0.65mm
U6: 74HC08; TSSOP-14_4.4x5mm_P0.65mm
U7: M29F800; TSOP-I-48_18.4x12mm_P0.5mm
U8: AS6C8016; TSOP-II-44_10.16x18.41mm_P0.8mm

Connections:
+5V: U5.6 (E3), U5.16 (VCC), U7.37 (VCC), U7.47 (~BYTE), U8.11 (VCC), U8.33 (VCC); also elsewhere on the board
A0: U1.9, U6.2; also elsewhere on the board
A1: U7.25 (A0), U8.5 (A0); also elsewhere on the board
A2: U7.24 (A1), U8.4 (A1); also elsewhere on the board
A3: U7.23 (A2), U8.3 (A2); also elsewhere on the board
A4: U7.22 (A3), U8.2 (A3); also elsewhere on the board
A5: U7.21 (A4), U8.1 (A4); also elsewhere on the board
A6: U7.20 (A5), U8.44 (A5); also elsewhere on the board
A7: U7.19 (A6), U8.43 (A6); also elsewhere on the board
A8: U7.18 (A7), U8.42 (A7); also elsewhere on the board
A9: U7.8 (A8), U8.28 (A8); also elsewhere on the board
A10: U7.7 (A9), U8.27 (A9); also elsewhere on the board
A11: U7.6 (A10), U8.26 (A10); also elsewhere on the board
A12: U7.5 (A11), U8.25 (A11); also elsewhere on the board
A13: U7.4 (A12), U8.24 (A12); also elsewhere on the board
A14: U7.3 (A13), U8.23 (A13); also elsewhere on the board
A15: U7.2 (A14), U8.22 (A14); also elsewhere on the board
A16: U7.1 (A15), U8.21 (A15); also elsewhere on the board
A17: U7.48 (A16), U8.20 (A16); also elsewhere on the board
A18: U7.17 (A17), U8.19 (A17); also elsewhere on the board
A19: U7.16 (A18), U8.18 (A18); also elsewhere on the board
A20: U5.1 (A0), U7.9 (A19); also elsewhere on the board
A21: U5.2 (A1); also elsewhere on the board
A22: U5.3 (A2); also elsewhere on the board
A23: U5.5 (E2); also elsewhere on the board
B/~W: U6.1, U6.4; also elsewhere on the board
D0: U7.29 (Q0), U8.7 (Q0); also elsewhere on the board
D1: U7.31 (Q1), U8.8 (Q1); also elsewhere on the board
D2: U7.33 (Q2), U8.9 (Q2); also elsewhere on the board
D3: U7.35 (Q3), U8.10 (Q3); also elsewhere on the board
D4: U7.38 (Q4), U8.13 (Q4); also elsewhere on the board
D5: U7.40 (Q5), U8.14 (Q5); also elsewhere on the board
D6: U7.42 (Q6), U8.15 (Q6); also elsewhere on the board
D7: U7.44 (Q7), U8.16 (Q7); also elsewhere on the board
D8: U7.30 (Q8), U8.29 (Q8); also elsewhere on the board
D9: U7.32 (Q9), U8.30 (Q9); also elsewhere on the board
D10: U7.34 (Q10), U8.31 (Q10); also elsewhere on the board
D11: U7.36 (Q11), U8.32 (Q11); also elsewhere on the board
D12: U7.39 (Q12), U8.35 (Q12); also elsewhere on the board
D13: U7.41 (Q13), U8.36 (Q13); also elsewhere on the board
D14: U7.43 (Q14), U8.37 (Q14); also elsewhere on the board
D15: U7.45 (Q15), U8.38 (Q15); also elsewhere on the board
GND: U5.8 (GND), U7.27 (GND), U7.46 (GND), U8.12 (VSS), U8.34 (VSS); also elsewhere on the board
unnamed: JP2.1 (A), U6.3
unnamed: JP3.1 (A), U6.6
unnamed: JP4.1 (A), U5.14 (O1)
unnamed: U1.8, U6.5
R~W: U7.11 (~WE), U8.17 (~WE); also elsewhere on the board
~0SEL: JP5.1 (A), U5.15 (O0); also elsewhere on the board
~2SEL: JP5.3 (B), U5.13 (O2); also elsewhere on the board
~3SEL: U5.12 (O3); also elsewhere on the board
~4SEL: U5.11 (O4); also elsewhere on the board
~5SEL: U5.10 (O5); also elsewhere on the board
~6SEL: U5.9 (O6); also elsewhere on the board
~DS: U5.4 (E1); also elsewhere on the board
~IOSEL: U5.7 (O7); also elsewhere on the board
~LDS: JP3.2 (B), U8.39 (~LB); also elsewhere on the board
~RAMSEL: JP4.2 (B), U8.6 (~CE); also elsewhere on the board
~RD: U7.28 (~OE), U8.41 (~OE); also elsewhere on the board
~ROMSEL: JP5.2 (C), U7.26 (~CS); also elsewhere on the board
~UDS: JP2.2 (B), U8.40 (~UB); also elsewhere on the board

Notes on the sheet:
NOTE: PIN 9 IS A19 ON M29F160, N/C ON M29F800

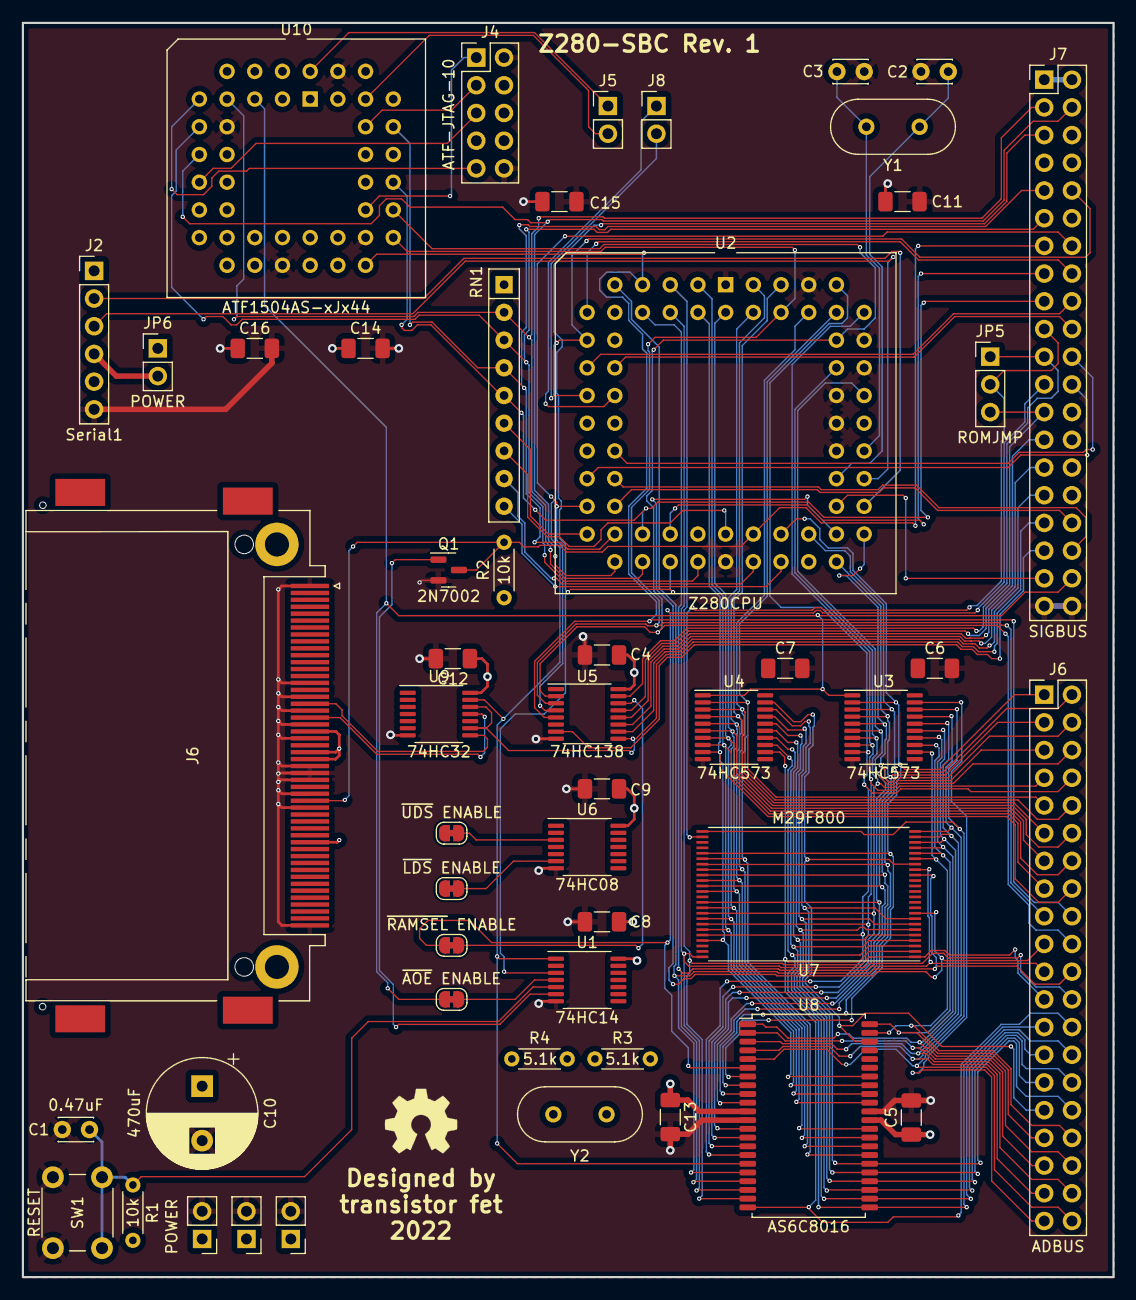
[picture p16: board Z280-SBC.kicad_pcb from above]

Board: 4 copper layers, 100.0 x 115.0 mm, 51 parts (0 on the bottom side), 107 nets.

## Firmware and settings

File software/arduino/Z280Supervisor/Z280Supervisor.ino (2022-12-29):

#define SERIAL_SPEED	115200

#define MEM_ADDR	0x100000
#define MEM_SIZE	4096

#define FLASH_ADDR	0x200000

#define ZBUS_XADDR_PORT	PORTF
#define ZBUS_XADDR_PIN	PINF
#define ZBUS_XADDR_DDR	DDRF

#define ZBUS_HADDR_PORT	PORTC
#define ZBUS_HADDR_PIN	PINC
#define ZBUS_HADDR_DDR	DDRC

#define ZBUS_LADDR_PORT	PORTL
#define ZBUS_LADDR_PIN	PINL
#define ZBUS_LADDR_DDR	DDRL
#define ZBUS_A0		9

#define ZBUS_LDATA_PORT	PORTA
#define ZBUS_LDATA_PIN	PINA
#define ZBUS_LDATA_DDR	DDRA

#define ZBUS_HDATA_PORT	PORTK
#define ZBUS_HDATA_PIN	PINK
#define ZBUS_HDATA_DDR	DDRK

#define ZBUS_WAIT	38 // PD7
#define ZBUS_BUSACK	39 // PG2
//#define ZBUS_BGACK	40 // PG1
#define ZBUS_BUSREQ	41 // PG0

#define ZBUS_DS		8
#define ZBUS_AS		50 // PB3
#define ZBUS_UDS	51 // PB2
#define ZBUS_LDS	52 // PB1
#define ZBUS_RW		53 // PB0

#define ZBUS_BW		7

#define ZBUS_WAIT_RESET 6

#define ZBUS_RESET	10 // PB4
#define ZBUS_BERR	11 // PB5

#define ZBUS_IS_AS()	(!(PINB & 0x08))
#define ZBUS_IS_UDS()	(!(PINB & 0x04))
#define ZBUS_IS_LDS()	(!(PINB & 0x02))
#define ZBUS_IS_WRITE()	(!(PINB & 0x01))
#define ZBUS_IS_READ()	(PINB & 0x01)

#define ZBUS_INIT_WAIT()	{ digitalWrite(ZBUS_WAIT, 0); pinMode(ZBUS_WAIT, INPUT); }
#define ZBUS_ASSERT_WAIT()	(DDRD |= 0x80)
#define ZBUS_UNASSERT_WAIT()	(DDRD &= ~(0x80))

#define ZBUS_INIT_RESET()	{ digitalWrite(ZBUS_RESET, 0); pinMode(ZBUS_RESET, INPUT); }
#define ZBUS_ASSERT_RESET()	(pinMode(ZBUS_RESET, OUTPUT))
#define ZBUS_UNASSERT_RESET()	(pinMode(ZBUS_RESET, INPUT))

#define ZBUS_RESET_WAIT()	{ PORTH |= 0x08; PORTH &= ~0x08; }
#define ZBUS_CLEAR_WAIT()	{ PORTH &= ~0x08; }

#undef INLINE_NOP
#define INLINE_NOP		__asm__("nop\n\t");

#define BUS_DEVICE	0
#define BUS_CONTROLLER	1

byte bus_request = 0;
byte bus_mode = BUS_DEVICE;

#define TTY_COMMAND	0
#define TTY_PASS	1

byte tty_mode = TTY_COMMAND;

void cpu_stop();

void enable_bus_interrupt(byte pin)
{
	*digitalPinToPCMSK(pin) |= bit (digitalPinToPCMSKbit(pin));  // enable pin
	PCIFR |= bit (digitalPinToPCICRbit(pin)); // clear any outstanding interrupt
	PCICR |= bit (digitalPinToPCICRbit(pin)); // enable interrupt for the group
}

void disable_bus_interrupt(byte pin)
{
	PCICR &= ~(bit (digitalPinToPCICRbit(pin))); // disable interrupt for the group
}

void init_bus()
{
	pinMode(ZBUS_BUSREQ, OUTPUT);
	digitalWrite(ZBUS_BUSREQ, 1);
	pinMode(ZBUS_BUSACK, INPUT);
	// WARNING don't use with CPU in, will drive BUSACK to turn off the latches
	//pinMode(ZBUS_BUSACK, OUTPUT);
	//digitalWrite(ZBUS_BUSACK, 0);

	pinMode(ZBUS_UDS, INPUT);
	pinMode(ZBUS_LDS, INPUT);

	pinMode(ZBUS_WAIT_RESET, OUTPUT);
	digitalWrite(ZBUS_WAIT_RESET, 0);
}

void take_bus()
{
	digitalWrite(ZBUS_BUSREQ, 0);
	while (digitalRead(ZBUS_BUSACK) && !digitalRead(ZBUS_AS)) { }
}

void release_bus()
{
	digitalWrite(ZBUS_BUSREQ, 1);
}

void set_bus_mode_controller()
{
	disable_bus_interrupt(ZBUS_AS);

	take_bus();

	// Controls
	pinMode(ZBUS_AS, OUTPUT);
	pinMode(ZBUS_DS, OUTPUT);
	pinMode(ZBUS_RW, OUTPUT);
	pinMode(ZBUS_BW, OUTPUT);
	pinMode(ZBUS_WAIT, INPUT);
	digitalWrite(ZBUS_AS, 1);
	digitalWrite(ZBUS_RW, 1);
	digitalWrite(ZBUS_BW, 0);

	// Address Bus
	ZBUS_XADDR_PORT = 0x00;	// A17 - A23
	ZBUS_XADDR_DDR = 0x7F;
	ZBUS_HADDR_PORT = 0x00;	// A9 - A16
	ZBUS_HADDR_DDR = 0xFF;
	ZBUS_LADDR_PORT = 0x00;	// A1 - A8
	ZBUS_LADDR_DDR = 0xFF;
	pinMode(ZBUS_A0, OUTPUT);

	// Data Bus
	ZBUS_LDATA_PORT = 0x00;	// D0 - D7
	ZBUS_LDATA_DDR = 0x00;
	ZBUS_HDATA_PORT = 0x00;	// D8 - D15
	ZBUS_HDATA_DDR = 0x00;

	tty_mode = TTY_COMMAND;
	bus_mode = BUS_CONTROLLER;
}

void set_bus_mode_device()
{
	// Controls
	pinMode(ZBUS_AS, INPUT);
	pinMode(ZBUS_DS, INPUT);
	pinMode(ZBUS_RW, INPUT);
	pinMode(ZBUS_BW, INPUT);

	ZBUS_INIT_WAIT();

	// Address Bus
	ZBUS_XADDR_PORT = 0x00;	// A17 - A23
	ZBUS_XADDR_DDR = 0x00;
	ZBUS_HADDR_PORT = 0x00;	// A9 - A16
	ZBUS_HADDR_DDR = 0x00;
	ZBUS_LADDR_PORT = 0x00;	// A1 - A8
	ZBUS_LADDR_DDR = 0x00;
	pinMode(ZBUS_A0, INPUT);

	// Data Bus
	ZBUS_LDATA_PORT = 0x00;	// D0 - D7
	ZBUS_LDATA_DDR = 0x00;
	ZBUS_HDATA_PORT = 0x00;	// D8 - D15
	ZBUS_HDATA_DDR = 0x00;

	// TODO remove after testing, disable the interrupt
	//enable_bus_interrupt(ZBUS_AS);
	ZBUS_CLEAR_WAIT();
	bus_mode = BUS_DEVICE;
}

/******************************
 * Serial Communications Code *
 ******************************/

#define SERIAL_SIZE	64

char serial_read_tail = 0;
char serial_read_head = 0;
char serial_avail = 0;
char serial_rb[SERIAL_SIZE];
char serial_write_head = 0;
char serial_write_tail = 0;
char serial_wb[SERIAL_SIZE];

byte read_serial()
{
	register char b;

	b = Serial.read();
	if (b == -1)
		return 0;

	if (tty_mode == TTY_PASS) {
		if (b == '`') {
			cpu_stop();
			set_bus_mode_controller();
			clear_read_buffer();
			return 0;
		}

		noInterrupts();
		//if (serial_read_head == serial_read_tail) {
		//	serial_read_head = 0;
		//	serial_read_tail = 0;
		//}

		serial_rb[serial_read_tail++] = b;
		if (serial_read_tail >= SERIAL_SIZE)
			serial_read_tail = 0;
		interrupts();
		//Serial.write(serial_get_byte());
		return 0;
	}
	else if (tty_mode == TTY_COMMAND) {
		noInterrupts();
		serial_rb[serial_read_tail] = b;
		if (b == '\n' || b == '\r') {
			serial_rb[serial_read_tail] = '\0';
			serial_avail = 1;
		}
		if (serial_read_tail < SERIAL_SIZE)
			serial_read_tail++;
		interrupts();
		return serial_avail;
	}
}

inline byte serial_get_byte()
{
	register byte value;

	noInterrupts();
	if (serial_read_head == serial_read_tail) {
		//clear_read_buffer();
		value = -1;
	} else {
		value = serial_rb[serial_read_head++];
		if (serial_read_head >= SERIAL_SIZE)
			serial_read_head = 0;
	}
	interrupts();
	return value;
}

inline byte serial_add_byte(byte data)
{
	noInterrupts();
	serial_wb[serial_write_tail++] = data;
	interrupts();
}

void clear_read_buffer()
{
	noInterrupts();
	serial_avail = 0;
	serial_read_head = 0;
	serial_read_tail = 0;
	interrupts();
}

void flush_write_buffer()
{
	if (serial_write_tail > 0) {
		byte is_running = bus_mode == BUS_DEVICE;
		take_bus();
		noInterrupts();
		for (byte i = 0; i < serial_write_tail; i++) {
			Serial.write(serial_wb[i]);
		}
		serial_write_head = 0;
		serial_write_tail = 0;
		interrupts();
		if (is_running)
			release_bus();
	}
}


#define ROM_SIZE	0x1800
#define ROM_MEM_SIZE	0x1800
word mem_size = ROM_MEM_SIZE;
byte mem[ROM_MEM_SIZE] = {
//// Welcome - Test Stack, No External Ram: 512
//0xc3, 0x80, 0x00, 0x00, 0x00, 0x00, 0x00, 0x00, 0x00, 0x00, 0x00, 0x00, 0x00, 0x00, 0x00, 0x00, 0x00, 0x00, 0x00, 0x00, 0x00, 0x00, 0x00, 0x00, 0x00, 0x00, 0x00, 0x00, 0x00, 0x00, 0x00, 0x00, 0x00, 0x00, 0x00, 0x00, 0x00, 0x00, 0x00, 0x00, 0x00, 0x00, 0x00, 0x00, 0x00, 0x00, 0x00, 0x00, 0x00, 0x00, 0x00, 0x00, 0x00, 0x00, 0x00, 0x00, 0x00, 0x00, 0x00, 0x00, 0x00, 0x00, 0x00, 0x00, 0x00, 0x00, 0x00, 0x00, 0x00, 0x00, 0x00, 0x00, 0x00, 0x00, 0x00, 0x00, 0x00, 0x00, 0x00, 0x00, 0x00, 0x00, 0x00, 0x00, 0x00, 0x00, 0x00, 0x00, 0x00, 0x00, 0x00, 0x00, 0x00, 0x00, 0x00, 0x00, 0x00, 0x00, 0x00, 0x00, 0x00, 0x00, 0x00, 0x00, 0x00, 0x00, 0x00, 0x00, 0x00, 0x00, 0x00, 0x00, 0x00, 0x00, 0x00, 0x00, 0x00, 0x00, 0x00, 0x00, 0x00, 0x00, 0x00, 0x00, 0x00, 0x00, 0x00, 0x00, 0x31, 0x00, 0x02, 0xcd, 0x87, 0x00, 0x76, 0x3e, 0x01, 0xd3, 0xff, 0x11, 0x9b, 0x00, 0x1a, 0xfe, 0x00, 0xca, 0x9a, 0x00, 0xd3, 0xfe, 0x13, 0xc3, 0x8e, 0x00, 0xc9, 0x57, 0x65, 0x6c, 0x63, 0x6f, 0x6d, 0x65, 0x20, 0x54, 0x6f, 0x20, 0x42, 0x72, 0x65, 0x61, 0x64, 0x38, 0x30, 0x21, 0x0a, 0x0a, 0x00, 0x00, 0x00, 0x00, 0x00, 0x00, 0x00, 0x00, 0x00, 0x00, 0x00, 0x00, 0x00, 0x00, 0x00, 0x00, 0x00, 0x00, 0x00, 0x00, 0x00, 0x00, 0x00, 0x00, 0x00, 0x00, 0x00, 0x00, 0x00, 0x00, 0x00, 0x00, 0x00, 0x00, 0x00, 0x00, 0x00, 0x00, 0x00, 0x00, 0x00, 0x00, 0x00, 0x00, 0x00, 0x00, 0x00, 0x00, 0x00, 0x00, 0x00, 0x00, 0x00, 0x00, 0x00, 0x00, 0x00, 0x00, 0x00, 0x00, 0x00, 0x00, 0x00, 0x00, 0x00, 0x00, 0x00, 0x00, 0x00, 0x00, 0x00, 0x00, 0x00, 0x00, 0x00, 0x00, 0x00, 0x00, 0x00, 0x00, 0x00, 0x00, 0x00, 0x00, 0x00, 0x00, 0x00, 0x00, 0x00, 0x00, 0x00, 0x00, 0x00, 0x00, 0x00, 0x00, 0x00, 0x00, 0x00, 0x00, 0x00, 0x00, 0x00, 0x00, 0x00, 0x00, 0x00, 0x00, 0x00, 0x00, 0x00, 0x00, 0x00, 0x00, 0x00, 0x00, 0x00, 0x00, 0x00, 0x00, 0x00, 0x00, 0x00, 0x00, 0x00, 0x00, 0x00, 0x00, 0x00, 0x00, 0x00, 0x00, 0x00, 0x00, 0x00, 0x00, 0x00, 0x00, 0x00, 0x00, 0x00, 0x00, 0x00, 0x00, 0x00, 0x00, 0x00, 0x00, 0x00, 0x00, 0x00, 0x00, 0x00, 0x00, 0x00, 0x00, 0x00, 0x00, 0x00, 0x00, 0x00, 0x00, 0x00, 0x00, 0x00, 0x00, 0x00, 0x00, 0x00, 0x00, 0x00, 0x00, 0x00, 0x00, 0x00, 0x00, 0x00, 0x00, 0x00, 0x00, 0x00, 0x00, 0x00, 0x00, 0x00, 0x00, 0x00, 0x00, 0x00, 0x00, 0x00, 0x00, 0x00, 0x00, 0x00, 0x00, 0x00, 0x00, 0x00, 0x00, 0x00, 0x00, 0x00, 0x00, 0x00, 0x00, 0x00, 0x00, 0x00, 0x00, 0x00, 0x00, 0x00, 0x00, 0x00, 0x00, 0x00, 0x00, 0x00, 0x00, 0x00, 0x00, 0x00, 0x00, 0x00, 0x00, 0x00, 0x00, 0x00, 0x00, 0x00, 0x00, 0x00, 0x00, 0x00, 0x00, 0x00, 0x00, 0x00, 0x00, 0x00, 0x00, 0x00, 0x00, 0x00, 0x00, 0x00, 0x00, 0x00, 0x00, 0x00, 0x00, 0x00, 0x00, 0x00, 0x00, 0x00, 0x00, 0x00, 0x00, 0x00, 0x00, 0x00, 0x00, 0x00, 0x00, 0x00, 0x00, 0x00, 0x00, 0x00, 0x00, 0x00, 0x00, 0x00, 0x00, 0x00, 0x00, 0x00, 0x00, 0x00, 0x00, 0x00, 0x00, 0x00, 0x00, 0x00, 0x00, 0x00, 0x00, 0x00, 0x00, 0x00, 0x00, 0x00, 0x00, 0x00, 0x00, 0x00, 0x00, 0x00, 0x00, 0x00, 0x00, 0x00, 0x00, 0x00, 0x00, 0x00, 0x00, 0x00, 0x00, 0x00, 0x00, 0x00, 0x00, 0x00, 0x00, 0x00, 0x00, 0x00, 0x00, 0x00, 0x00, 0x00, 0x00, 0x00, 0x00, 0x00, 0x00, 0x00, 0x00, 0x00, 0x00, 0x00, 0x00, 0x00, 
#include "/media/work/z280/software/monitor.txt"
};

#define READ_BUS_DEBUG	1
#define WRITE_BUS_DEBUG	1
#define WRITE_PROTECT	1
#define IO_SPACE_HADDR	(0x20 >> 1)	// address 0x2000

char trace = 0;

ISR (PCINT0_vect) __attribute__ ((naked));
ISR (PCINT0_vect) {
	// The request handling has been moved out of the interrput so that the serial port interrupt is
	// not blocked for the entirety of the request, which is the bulk of the work the ardunio is doing
	// when the CPU is running
	if (ZBUS_IS_AS()) {
		//ZBUS_ASSERT_WAIT();
		bus_request = 1;
	}

	/*
	asm(
	"push	r0\n"
	"in	r0, 0x3f\n"
	"push	r0\n"
	"push	r1\n"

	"in	r0, %0\n"
	"in	r1, %1\n"
	"bst	r0, 0x3\n"
	"bld	r1, 0x7\n"
	"out	%1, r1\n"
	"sts	%2, r1\n"

	"pop	r1\n"
	"pop	r0\n"
	"out	0x3f, r0\n"
	"pop	r0\n"
	"reti\n"
	: : "I" (_SFR_IO_ADDR(PINB)), "I" (_SFR_IO_ADDR(DDRD)), "m" (bus_request) :
	);
	*/
}

void check_bus_cycle()
{
	if (!bus_request)
		return;

	//noInterrupts();
	PCICR = 0x00;
	PCIFR = 0x00;
	bus_request = 0;

	register uint32_t addr = ((((ZBUS_XADDR_PIN & 0x7F) << 16) | (ZBUS_HADDR_PIN << 8) | ZBUS_LADDR_PIN) << 1);
	if (addr < 0x4000) {
		noInterrupts();

		// Read Operation
		if (ZBUS_IS_READ()) {
			ZBUS_HDATA_DDR = 0xFF;
			ZBUS_LDATA_DDR = 0xFF;

			//#if READ_BUS_DEBUG
			if (READ_BUS_DEBUG || (trace && addr >= ROM_SIZE)) {
				Serial.write('R');
				Serial.print(addr, HEX);
				if (addr < mem_size) {
					Serial.write('|');
					Serial.print((mem[addr] << 8) | mem[addr + 1], HEX);
				}
				Serial.write('\n');
			}
			//#endif

			if (ZBUS_HADDR_PIN == IO_SPACE_HADDR) {
				//Serial.write('S');
				//Serial.write('\n');
				switch (ZBUS_LADDR_PIN) {
				    case 0x01:
					ZBUS_LDATA_PORT = ((serial_read_head != serial_read_tail) ? 0x01 : 0x00) | ((serial_write_head == serial_write_tail) ? 0x04 : 0x00);
					break;
				    case 0x03:
					register byte val = serial_get_byte();
					//Serial.write(val);
					ZBUS_LDATA_PORT = val;
					break;
				    case 0x0e:
					ZBUS_LDATA_PORT = digitalRead(13);
					break;
				    default:
					break;
				}
			}
			else {
				if (ZBUS_IS_LDS())
					ZBUS_LDATA_PORT = (addr < mem_size) ? mem[addr] : 0x00;
				if (ZBUS_IS_UDS())
					ZBUS_HDATA_PORT = (addr < mem_size) ? mem[addr + 1] : 0x00;
			}
		}
		// Write Operation
		else {
			//#if WRITE_BUS_DEBUG
			if (WRITE_BUS_DEBUG || (trace && addr >= ROM_SIZE)) {
				Serial.write('W');
				Serial.print(addr, HEX);
				Serial.write('|');
				register word data = (ZBUS_HDATA_PIN << 8) | ZBUS_LDATA_PIN;
				Serial.print(data, HEX);
				Serial.write('\n');
			}
			//#endif

			if (ZBUS_HADDR_PIN == IO_SPACE_HADDR) {
				//Serial.write('X');
				//Serial.write('\n');
				switch (ZBUS_LADDR_PIN) {
				    case 0x03:
					Serial.write(ZBUS_LDATA_PIN);
					//serial_add_byte(ZBUS_LDATA_PIN);
					break;
				    case 0x0c:
					trace = (ZBUS_LDATA_PIN & 0x01);
					Serial.println(trace ? "Trace On" : "Trace Off");
					break;
				    case 0x0e:
					digitalWrite(13, (ZBUS_LDATA_PIN & 0x01));
					break;
				    default:
					break;
				}
			}
			else if (addr < mem_size) {
				if (!WRITE_PROTECT || addr >= ROM_SIZE) {
					if (ZBUS_IS_LDS())
						mem[addr] = ZBUS_LDATA_PIN;
					if (ZBUS_IS_UDS())
						mem[addr + 1] = ZBUS_HDATA_PIN;
				}
			}
		}


		ZBUS_LDATA_DDR = 0x00;
		ZBUS_HDATA_DDR = 0x00;
		interrupts();
	}

	ZBUS_UNASSERT_WAIT();
	INLINE_NOP;
	INLINE_NOP;
	PCICR = 0x01;
}

//
// Print debug information on the bus cycles and provide WAIT signal without responding to the request
//
// This is used when the computer jumpers are set to run the program from the onboard Flash memory, but allows
// each memory access to be observed
//
void snoop_bus_cycle()
{
	if (!bus_request)
		return;

	bus_request = 0;
	PCICR = 0x00;
	PCIFR = 0x00;

	register uint32_t addr = ((ZBUS_XADDR_PIN & 0x7F) << 17) | (ZBUS_HADDR_PIN << 9) | (ZBUS_LADDR_PIN << 1);
	if (ZBUS_IS_READ()) {
		Serial.write('R');
	}
	else {
		Serial.write('W');
	}

	Serial.print(addr, HEX);
	Serial.write('|');
	register uint16_t data = (ZBUS_HDATA_PIN << 8) | ZBUS_LDATA_PIN;
	Serial.print(data, HEX);
	//Serial.write(type ? 'w' : 'b');
	Serial.write('\n');

	PCICR = 0x01;
	//interrupts();
	ZBUS_UNASSERT_WAIT();
	//ZBUS_RESET_WAIT();
}


inline void write_data(uint32_t addr, uint16_t data)
{
	ZBUS_HDATA_DDR = 0xFF;
	ZBUS_LDATA_DDR = 0xFF;

	ZBUS_HDATA_PORT = (uint8_t) (data >> 8);
	ZBUS_LDATA_PORT = (uint8_t) data;

	ZBUS_XADDR_PORT = (uint8_t) (addr >> 17) & 0x7F;
	ZBUS_HADDR_PORT = (uint8_t) (addr >> 9);
	ZBUS_LADDR_PORT = (uint8_t) (addr >> 1);
	digitalWrite(ZBUS_A0, addr & 0x01);

	digitalWrite(ZBUS_BW, 0);
	digitalWrite(ZBUS_RW, 0);
	digitalWrite(ZBUS_DS, 0);
	//delayMicroseconds(1);
	INLINE_NOP;
	INLINE_NOP;
	digitalWrite(ZBUS_DS, 1);
	digitalWrite(ZBUS_RW, 1);
	INLINE_NOP;

	ZBUS_HDATA_PORT = 0x00;
	ZBUS_LDATA_PORT = 0x00;
	ZBUS_XADDR_PORT = 0x00;
	ZBUS_HADDR_PORT = 0x00;
	ZBUS_LADDR_PORT = 0x00;

	ZBUS_HDATA_DDR = 0x00;
	ZBUS_LDATA_DDR = 0x00;
}

inline uint16_t read_data(uint32_t addr)
{
	uint8_t hvalue = 0;
	uint8_t lvalue = 0;

	ZBUS_HDATA_DDR = 0x00;
	ZBUS_LDATA_DDR = 0x00;

	ZBUS_XADDR_PORT = (uint8_t) (addr >> 17) & 0x7F;
	ZBUS_HADDR_PORT = (uint8_t) (addr >> 9);
	ZBUS_LADDR_PORT = (uint8_t) (addr >> 1);
	digitalWrite(ZBUS_A0, addr & 0x01);

	digitalWrite(ZBUS_BW, 0);
	digitalWrite(ZBUS_RW, 1);
	digitalWrite(ZBUS_DS, 0);
	//delayMicroseconds(1);
	INLINE_NOP;
	hvalue = ZBUS_HDATA_PIN;
	lvalue = ZBUS_LDATA_PIN;
	digitalWrite(ZBUS_DS, 1);
	INLINE_NOP;

	ZBUS_HDATA_PORT = 0x00;
	ZBUS_LDATA_PORT = 0x00;
	ZBUS_XADDR_PORT = 0x00;
	ZBUS_HADDR_PORT = 0x00;
	ZBUS_LADDR_PORT = 0x00;

	return ((uint16_t) hvalue << 8) | (uint16_t) lvalue;
}

void run_read_test(int argc, char **argv)
{
	int errors = 0;

	uint32_t start_addr = (argc >= 2) ? strtol(argv[1], NULL, 16) : MEM_ADDR;
	uint32_t size = (argc >= 3) ? strtol(argv[2], NULL, 16) : MEM_SIZE;

	set_bus_mode_controller();
	Serial.print("Running Read Test\n");

	for (uint32_t i = 0; i < size / 2; i++) {
		uint32_t addr = start_addr + (i << 1);
		uint16_t data = read_data(addr);

		if (data != i)
			errors += 1;

		if (i % 32 == 0) {
			Serial.print("\n");
			Serial.print(addr, HEX);
			Serial.print(" ");
		}

		if (data < 0x10) Serial.print("000");
		else if (data < 0x100) Serial.print("00");
		else if (data < 0x1000) Serial.print("0");
		Serial.print(data, HEX);
		Serial.print(" ");
	}

	Serial.print("\n");
	Serial.print("Errors: ");
	Serial.print(errors, DEC);
	Serial.print("\n");
}

void run_quiet_read_test(int argc, char **argv)
{
	int errors = 0;

	uint32_t start_addr = (argc >= 2) ? strtol(argv[1], NULL, 16) : MEM_ADDR;
	uint32_t size = (argc >= 3) ? strtol(argv[2], NULL, 16) : MEM_SIZE;

	set_bus_mode_controller();
	Serial.print("Running Read Test\n");

	for (uint32_t i = 0; i < size / 2; i++) {
		uint32_t addr = start_addr + (i << 1);
		uint16_t data = read_data(addr);

		if (data != i)
			errors += 1;
	}

	Serial.print("\n");
	Serial.print("Errors: ");
	Serial.print(errors, DEC);
	Serial.print("\n");
}

void run_write_test(int argc, char **argv)
{
	uint32_t start_addr = (argc >= 2) ? strtol(argv[1], NULL, 16) : MEM_ADDR;
	uint32_t size = (argc >= 3) ? strtol(argv[2], NULL, 16) : MEM_SIZE;

	set_bus_mode_controller();
	Serial.print("Running Write Test\n");

	digitalWrite(ZBUS_RW, 1);
	digitalWrite(ZBUS_AS, 1);

	for (uint32_t i = 0; i < size / 2; i++) {
		write_data(start_addr + (i << 1), i);

		delayMicroseconds(1);

		if ((i % 64) == 63) {
			delayMicroseconds(10000);
		}
	}

	Serial.print("Complete\n");
}


void run_erase_flash(int argc, char **argv)
{
	uint32_t flash_addr = (argc >= 2) ? strtol(argv[1], NULL, 16) : FLASH_ADDR;

	Serial.println("Erasing flash");
	write_data(flash_addr + (0x555 << 1), 0xAAAA);
	write_data(flash_addr + (0x2AA << 1), 0x5555);
	write_data(flash_addr + (0x555 << 1), 0x8080);
	write_data(flash_addr + (0x555 << 1), 0xAAAA);
	write_data(flash_addr + (0x2AA << 1), 0x5555);
	write_data(flash_addr + 0x00, 0x3030);
}


void program_flash_data(uint32_t flash_addr, uint32_t addr, uint16_t data)
{
	write_data(flash_addr + (0x555 << 1), 0xAAAA);
	write_data(flash_addr + (0x2AA << 1), 0x5555);
	write_data(flash_addr + (0x555 << 1), 0xA0A0);
	write_data(addr, data);
}

void run_send_mem(int argc, char **argv)
{
	uint16_t i;
	uint32_t addr;

	uint32_t flash_addr = (argc >= 2) ? strtol(argv[1], NULL, 16) : FLASH_ADDR;

	set_bus_mode_controller();
	Serial.print("Writing data to flash to ");
	Serial.print(flash_addr, HEX);
	Serial.print("\n");

	for (addr = flash_addr; addr < flash_addr + mem_size; addr += 2) {
		uint16_t data = read_data(addr);
		if (data != 0xFFFF) {
			Serial.print("Flash not erased at ");
			Serial.print(addr, HEX);
			Serial.print(" (");
			Serial.print(data, HEX);
			Serial.print(")\n");
			return;
		}
	}

	for (i = 0, addr = flash_addr; i < mem_size; i += 2, addr += 2) {
		word data = (mem[i] << 8) | mem[i + 1];
		program_flash_data(flash_addr, addr, data);
		Serial.print(data, HEX);
		Serial.print(" ");

		if ((i % 64) == 62) {
			Serial.print("\n");
		}
	}

	Serial.print("Sending complete\n");
}

void run_verify_mem(int argc, char **argv)
{
	word i;
	long addr;

	uint32_t flash_addr = (argc >= 2) ? strtol(argv[1], NULL, 16) : FLASH_ADDR;

	set_bus_mode_controller();
	Serial.print("Verify flash data\n");

	for (i = 0, addr = flash_addr; i < mem_size; i += 2, addr += 2) {
		word data = (mem[i] << 8) | mem[i + 1];
		word actual_data = read_data(addr);
		if (data != actual_data) {
			Serial.print("Expected ");
			Serial.print(data, HEX);
			Serial.print(" but found ");
			Serial.print(actual_data, HEX);
			Serial.print("\n");
		}
	}

	Serial.print("Verify complete\n");
}


void run_flash_test()
{
	word value;

	write_data(0x555 << 1, 0xAAAA);
	write_data(0x2AA << 1, 0x5555);
	write_data(0x555 << 1, 0x9090);
	value = read_data(0x01 << 1);
	Serial.print(value, HEX);
	Serial.print("\n");
}


void cpu_start()
{
	set_bus_mode_device();
	tty_mode = TTY_PASS;
	release_bus();
	Serial.print("Running\n\n");
}

void cpu_stop()
{
	tty_mode = TTY_COMMAND;
	take_bus();
	set_bus_mode_controller();
	Serial.print("\nStopped");
}

void cpu_reset()
{
	ZBUS_ASSERT_RESET();
	delay(10);

	ZBUS_LDATA_DDR = 0xFF;
	ZBUS_LDATA_PORT = 0x8E;
	ZBUS_INIT_WAIT();
	ZBUS_ASSERT_WAIT();
	INLINE_NOP;
	INLINE_NOP;
	ZBUS_UNASSERT_RESET();
	INLINE_NOP;
	INLINE_NOP;
	INLINE_NOP;
	INLINE_NOP;
	ZBUS_ASSERT_WAIT();
	ZBUS_LDATA_DDR = 0x00;
}

int parseline(char *input, char **vargs)
{
	short j = 0;

	while (*input == ' ')
		input++;

	vargs[j++] = input;
	while (*input != '\0' && *input != '\n' && *input != '\r') {
		if (*input == ' ') {
			*input = '\0';
			input++;
			while (*input == ' ')
				input++;
			vargs[j++] = input;
		}
		else
 			input++;
	}

	*input = '\0';
	if (*vargs[j - 1] == '\0')
		j -= 1;
	vargs[j] = NULL;

	return j;
}

void do_command(String line)
{
	short argc;
	char *argv[10];
	argc = parseline(line.c_str(), argv);

	if (!strcmp(argv[0], "read")) {
		run_read_test(argc, argv);
	}
	else if (!strcmp(argv[0], "qread")) {
		run_quiet_read_test(argc, argv);
	}
	else if (!strcmp(argv[0], "write")) {
		run_write_test(argc, argv);
	}
	else if (!strcmp(argv[0], "send")) {
		run_send_mem(argc, argv);
	}
	else if (!strcmp(argv[0], "verify")) {
		run_verify_mem(argc, argv);
	}
	else if (!strcmp(argv[0], "erase")) {
		run_erase_flash(argc, argv);
	}
	else if (!strcmp(argv[0], "testflash")) {
		run_flash_test();
	}
	else if (!strcmp(argv[0], "run")) {
		cpu_reset();
		cpu_start();
	}
	else if (!strcmp(argv[0], "stop")) {
		cpu_stop();
	}
	else if (!strcmp(argv[0], "reset")) {
		set_bus_mode_device();
		cpu_reset();
	}
}

void setup()
{
	pinMode(13, OUTPUT);
	digitalWrite(13, 1);

	Serial.begin(SERIAL_SPEED);

	ZBUS_INIT_RESET();

	init_bus();

	set_bus_mode_controller();
	//set_bus_mode_device();

	digitalWrite(13, 0);
	Serial.print("> ");

	cpu_reset();
	cpu_stop();
	//cpu_start();
}

void loop()
{
	if (read_serial() && tty_mode == TTY_COMMAND) {
		String line = String(serial_rb);
		clear_read_buffer();
		Serial.print(line);
		Serial.print("\n");
		do_command(line);
		if (tty_mode == TTY_COMMAND)
			Serial.print("\n> ");
	}

	//check_bus_cycle();
	snoop_bus_cycle();
}

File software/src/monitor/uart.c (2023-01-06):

#include <stdint.h>

#include "z280.h"
#include "uart.h"


struct _FILE {
    uint16_t number;
};

FILE __stdout = { 0 };


// Initialize the UART and Timer1
void init_uart()
{
	SET_PAGE_REG(0xFE);

	//// Set Timer1 Configuration Register
	//OUT_u8(0xE8, 0xC8);	// Continuous, Retrigger, IPA=8

	//// Set Timer1 Time Constant Register
	//OUT_u16(0xEA, 23);

	//// Set Timer1 Command/Status Register
	//OUT_u8(0xE9, 0xF8);	// Enable, Gate=1, Trigger=1

	// Set UART Control Register
	//OUT_u8(0x10, 0xE8);
	// TODO this is now using the external clock source at f/32
	OUT_u8(0x10, 0xE4);

	// Set Transmit Control Register
	OUT_u8(0x12, 0x80);

	// Set Receive Control Register
	OUT_u8(0x14, 0x80);
}

int putchar(int ch) __naked
{
	__asm
	push	hl
	__endasm;

	SET_PAGE_REG(0xFE);

	__asm
	pop	hl

	; Check the transmit buffer empty flag until 0
    0001$:
	in	a, (0x12)
	bit	0, a
	jp	Z, 0001$

	; Write the character to output
	ld	a, l
	out	(0x18), a

	ld	hl, #0

	ret
	__endasm;
}

int getchar() __naked
{
	SET_PAGE_REG(0xFE);

	__asm
    0001$:
	in	a, (0x14)
	bit	4, a
	jp	Z, 0001$

	; Check if an error occurred
	bit	0, a
	jp	NZ, 0002$

	; Read in the next character and return
	in	a, (0x16)
	ld	d, #0
	ld	e, a

	ret

    0002$:
	or	a, #0xF0
	ld	d, #0
	ld	e, a

	; Discard the error byte
	in	a, (0x16)

	; Reset the error bits
	ld	a, #0x80
	out	(0x14), a

	ld	de, #0

	ret
	__endasm;
}

int puts(const char *str)
{
    for (; *str != 0; str++) {
	putchar(*str);
    }
    putchar('\n');
    return 0;
}

int fputs(const char *str, FILE *stream)
{
    for (; *str != 0; str++) {
	putchar(*str);
    }
    return 0;
}

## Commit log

2022-11-14 Initial commit (after completing most of the design already)
    I was trying to be fairly quick with the design, rather than prototyping
    beforehand, so there are likely a lot of mistakes and issue, but this
    is intended as a prototyping board, not a usable board, so it's ok if
    it's not right the first time, as long as it can be patched.
    [Bus.kicad_sch, IO.kicad_sch, Memory.kicad_sch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]
2022-11-21 Work in progress on PCB design, address and data buses mostly connected
    [Bus.kicad_sch, Z280-SBC.kicad_pcb, Z280-SBC.kicad_sch]
2022-11-26 Mostly done Rev1
    [IO.kicad_sch, Memory.kicad_sch, Z280-SBC.kicad_pcb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]
2022-11-27 Rev1 - All connections completed
    [Bus.kicad_sch, Memory.kicad_sch, Z280-SBC.kicad_sch]
2022-12-02 Z280-SBC Revision 1 is complete
    [Bus.kicad_sch, IO.kicad_sch, Memory.kicad_sch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]
2022-12-24 Board is built, but there are some problems with address lines
    [Z280-SBC.kicad_sch]
2022-12-28 Updated and fixed some hardware issues
    [Z280Supervisor.ino, welcome.asm]
2022-12-29 Fixed issues with MMU and added UART transmission
    [Z280Supervisor.ino, welcome.asm]
2023-01-02 Minor fixed from debugging
    [monitor.c, uart.c, welcome.asm]
2023-01-11 Fixed most of the issues with Rev.1
    [Bus.kicad_sch, IO.kicad_sch, Memory.kicad_sch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]
2023-01-11 Moved the CTIN pins to output pins on the CPLD
    [Bus.kicad_sch]
2023-08-07 Added computie-kicad-library and fixed references to point to it
    [Bus.kicad_sch, IO.kicad_sch, Memory.kicad_sch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]
2024-09-06 Added readme to board directory
